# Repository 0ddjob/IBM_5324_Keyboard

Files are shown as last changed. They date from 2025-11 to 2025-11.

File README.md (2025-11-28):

# IBM System/23 Model 5324 Keyboard
Recreation of the keyboard for this computer to bring those without keyboards back to life.

## [Design References](/Design_Reference)
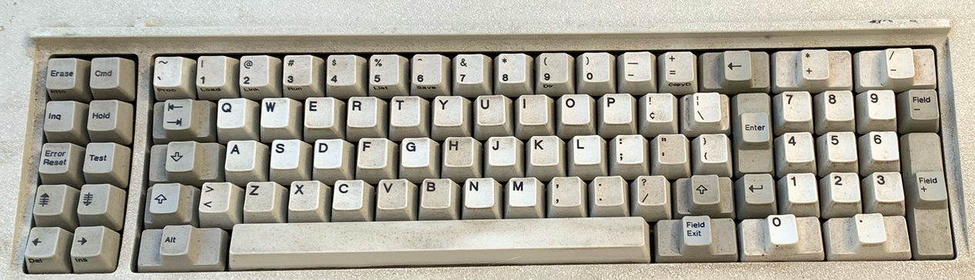
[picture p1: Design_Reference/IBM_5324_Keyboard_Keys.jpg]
Actual keyboard layout


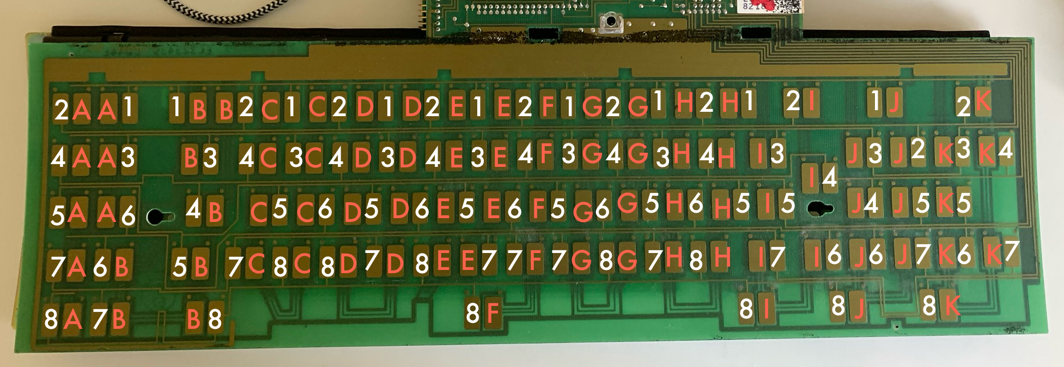
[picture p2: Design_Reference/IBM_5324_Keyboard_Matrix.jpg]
Keyboard matrix


| |Column A|Column B|Column C|Column D|Column E|Column F|Column G|Column H|Column I|Column J|Column K|
|-----|---|---|---|---|---|---|---|---|---|---|---|
|Row 1| 6F/7F  | 3E | 32 | 34 | 36 | 38 | 3A | 3C | | 4B | |
|Row 2| 7C | 31 | 33 | 35 | 37 | | 39 | 3B | 3D T | 48 | 4C |
|Row 3| 6D | 20 | 22 | 24 | 26 | | 28 | 2A | 2C | 47 | 49 |
|Row 4| 6C | 54/74  | 21 | 23 | 25 | 27 | 29 | 2B | 2D | 44 | 4E |
|Row 5| 6E | 57/77  | 11 | 13 | 15 | 17 | 19 | 1B | 59/79  | 45 | 46 |
|Row 6| 7D | 70 T | 12 | 14 | 16 | | 18 | 1A | 56/76  | 41 | 43 |
|Row 7| 71 T | 73 T | 0E | 03 | 05 | 06 | 07 | 09 | 0B/7B  | 42 | 4D |
|Row 8| 72 T | 7E/5E  | 01 | 02 | 04 | 0F T | 08 | 0A | 68/78  | 40 | 4A |

xx/yy = make/break key (send on release)<br>
T = typamatic key (repeat while held)<br>

## Keyboard Data Flow 
Refer p3-19 of the [SY34-0241-1 service manual.](/Datasheets/SY34-0241-1_IBM_5324_Computer_Service_Manual_May82_Keyboard.pdf)

The original keyboard uses a capacitive matrix where there is a capacitor for each key. When a key is pressed the capacitance increases.<br>

In my design we use standard key switches.<br>

The keyboard MCU has 11 drive lines to repeatedly scan the matrix - in my schematic these are the columns.<br>  

The increased capacitance of the active key's capacitor permits the drive-line (column) scan pulse to appear at one of the eight input lines to the sense amplifier - in my schematic these are the rows.<br>

The MCU uses the combination of the active drive line (column) and sense amplifier input line (row) to determine a scan code character (88 possible, 83 actually used).<br>

In my design the columns and rows are pulled high.  To scan the keyboard matrix we take each column low in turn.  A key press is detected when the key switch shorts the row to the column, taking the row low which is detected by the controller.  The combination of column and row is translated to a 5324 scan code and put on the bus via a buffer to ensure the 5324 accurately reads the code.<br>

An interrupt request is sent to the Model 5324 processing unit which will then read the scan code character.<br>

## Key Caps
[Key cap layout](https://gist.github.com/0ddjob/6a0642893fc0fdca74740a1e6c51e858)

|Size |Count|
|-----|-----|
|1u |68 |
|1.25u|2 |
|1.5u |2 |
|1.75u|2 |
|2u |6 |
|2.25u|1 |
|3u |1 |
|9.5u |1 |
|TOTAL|83 |

|Size|Key|
|-----|---|
|1.25u|Backslash|
|1.25u|Shift LH|
|1.5u|Shift RH|
|1.5u|Field Advance|
|1.75u|Backspace|
|1.75u|Shift Lock|
|2u|Field Exit|
|2u|NP +|
|2u|NP -|
|2u|NP 0|
|2u|NP .|
|2u|Alt|
|2u|Enter (vertical)|
|3u|Field + (vertical)|
|9.5u|Space|

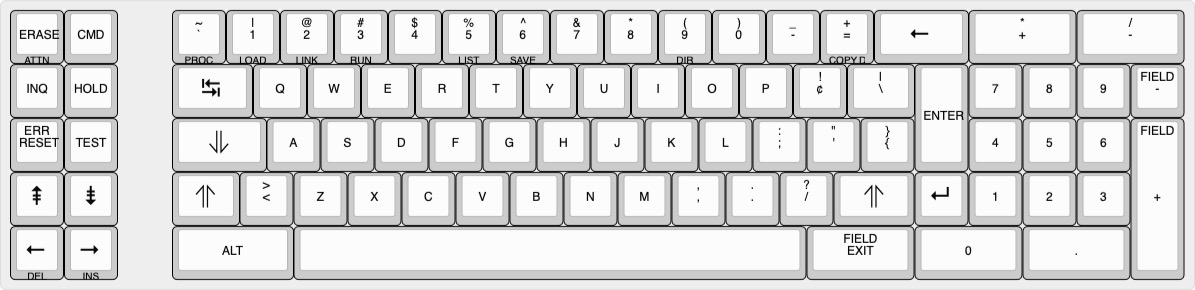
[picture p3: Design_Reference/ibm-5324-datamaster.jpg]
Keyboard layout


## [KiCad Design](/KiCad)
[Schematic](/IBM_5324_Keyboard_Schematic.pdf)

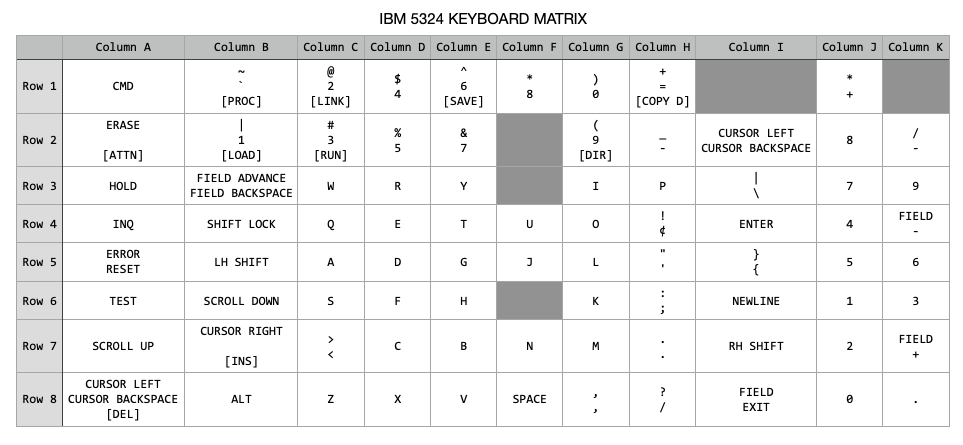
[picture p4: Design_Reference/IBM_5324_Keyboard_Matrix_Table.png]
Keyboard matrix layout


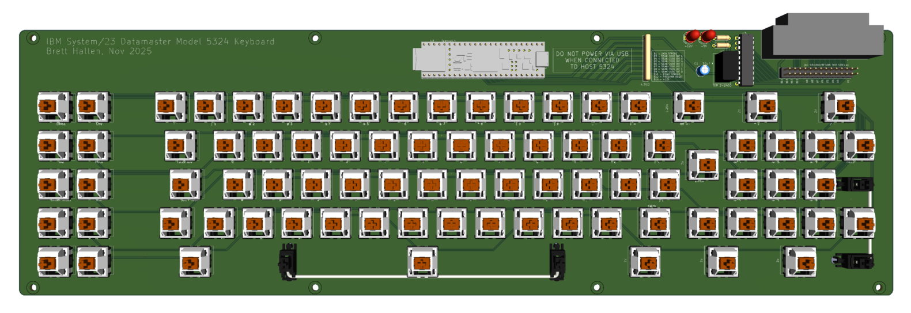
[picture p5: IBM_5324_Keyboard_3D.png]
Keyboard 3D


## [N-Key Rollover (NKRO) Design](/KiCad_NKRO)
Adding diodes to each key switch on their row connection.  The original keyboard doesn't have these so the modified behaviour might not be expected, thus it's "experimental".

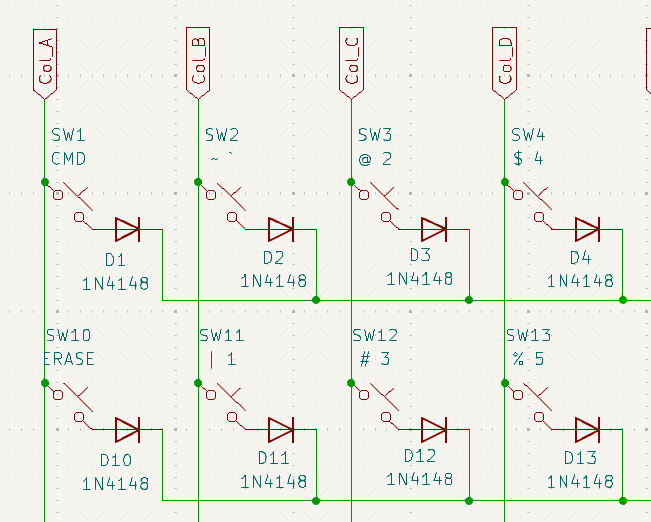
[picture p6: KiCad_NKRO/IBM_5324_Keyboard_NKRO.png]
KNRO schematic


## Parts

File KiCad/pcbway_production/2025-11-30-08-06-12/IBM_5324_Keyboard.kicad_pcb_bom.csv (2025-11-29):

Designator | Quantity | Value | Footprint | Package | MPN | DNP | Mount_Type | Description | Sim.Pins
C1 | 1 | 10µF | CP_Radial_D5.0mm_P2.50mm |  |  |  | tht | Polarized capacitor
C2, C3 | 2 | 100nF | C_Disc_D3.8mm_W2.6mm_P2.50mm |  |  |  | tht | Unpolarized capacitor
D1 | 1 | +5V | LED_D5.0mm |  |  |  | tht | Light emitting diode | 1=K 2=A
D2 | 1 | +12V | LED_D5.0mm |  |  |  | tht | Light emitting diode | 1=K 2=A
J1 | 1 | To 5324 | L717SDB25P1ACH3R |  |  |  | tht | 25-pin D-SUB connector, pins (male), Mounting Hole
J2 | 1 | To DB25 | PinHeader_2x14_P2.54mm_Vertical |  |  |  | tht | Generic connector, double row, 02x14, row letter first pin numbering scheme (pin number consists of a letter for the row and a number for the pin index in this row. a1, ..., aN; b1, ..., bN), script generated (kicad-library-utils/schlib/autogen/connector/)
KB1 | 1 | SPACE | Stabilizer_Cherry_MX_8.00u |  |  |  | tht
KB2 | 1 | FIELD+ | Stabilizer_Cherry_MX_3.00u |  |  |  | tht
R1, R2 | 2 | R | R_Axial_DIN0207_L6.3mm_D2.5mm_P7.62mm_Horizontal |  |  |  | tht | Resistor
RN1 | 1 | 4.7KΩ | R_Array_SIP9 |  |  |  | tht | 8 resistor network, star topology, bussed resistors, small symbol
SW1 | 1 | CMD | SW_Cherry_MX_PCB |  |  |  | tht | Push button switch, normally open, two pins, 45° tilted
SW10 | 1 | ERASE | SW_Cherry_MX_PCB |  |  |  | tht | Push button switch, normally open, two pins, 45° tilted
SW11 | 1 | | 1 | SW_Cherry_MX_PCB |  |  |  | tht | Push button switch, normally open, two pins, 45° tilted
SW12 | 1 | # 3 | SW_Cherry_MX_PCB |  |  |  | tht | Push button switch, normally open, two pins, 45° tilted
SW13 | 1 | % 5 | SW_Cherry_MX_PCB |  |  |  | tht | Push button switch, normally open, two pins, 45° tilted
SW14 | 1 | & 7 | SW_Cherry_MX_PCB |  |  |  | tht | Push button switch, normally open, two pins, 45° tilted
SW15 | 1 | ( 9 | SW_Cherry_MX_PCB |  |  |  | tht | Push button switch, normally open, two pins, 45° tilted
SW16 | 1 | _ - | SW_Cherry_MX_PCB |  |  |  | tht | Push button switch, normally open, two pins, 45° tilted
SW17 | 1 | RH <- | SW_Cherry_MX_PCB |  |  |  | tht | Push button switch, normally open, two pins, 45° tilted
SW18 | 1 | NP 8 | SW_Cherry_MX_PCB |  |  |  | tht | Push button switch, normally open, two pins, 45° tilted
SW19 | 1 | / - | SW_Cherry_MX_PCB_1.75u |  |  |  | tht | Push button switch, normally open, two pins, 45° tilted
SW2 | 1 | ~ ` | SW_Cherry_MX_PCB |  |  |  | tht | Push button switch, normally open, two pins, 45° tilted
SW20 | 1 | HOLD | SW_Cherry_MX_PCB |  |  |  | tht | Push button switch, normally open, two pins, 45° tilted
SW21 | 1 | FIELD ADV | SW_Cherry_MX_PCB_1.50u |  |  |  | tht | Push button switch, normally open, two pins, 45° tilted
SW22 | 1 | W | SW_Cherry_MX_PCB |  |  |  | tht | Push button switch, normally open, two pins, 45° tilted
SW23 | 1 | R | SW_Cherry_MX_PCB |  |  |  | tht | Push button switch, normally open, two pins, 45° tilted
SW24 | 1 | Y | SW_Cherry_MX_PCB |  |  |  | tht | Push button switch, normally open, two pins, 45° tilted
SW25 | 1 | I | SW_Cherry_MX_PCB |  |  |  | tht | Push button switch, normally open, two pins, 45° tilted
SW26 | 1 | P | SW_Cherry_MX_PCB |  |  |  | tht | Push button switch, normally open, two pins, 45° tilted
SW27 | 1 | | \ | SW_Cherry_MX_PCB |  |  |  | tht | Push button switch, normally open, two pins, 45° tilted
SW28 | 1 | NP 7 | SW_Cherry_MX_PCB |  |  |  | tht | Push button switch, normally open, two pins, 45° tilted
SW29 | 1 | NP 9 | SW_Cherry_MX_PCB |  |  |  | tht | Push button switch, normally open, two pins, 45° tilted
SW3 | 1 | @ 2 | SW_Cherry_MX_PCB |  |  |  | tht | Push button switch, normally open, two pins, 45° tilted
SW30 | 1 | INQ | SW_Cherry_MX_PCB |  |  |  | tht | Push button switch, normally open, two pins, 45° tilted
SW31 | 1 | SHIFT LOCK | SW_Cherry_MX_PCB_1.75u |  |  |  | tht | Push button switch, normally open, two pins, 45° tilted
SW32 | 1 | Q | SW_Cherry_MX_PCB |  |  |  | tht | Push button switch, normally open, two pins, 45° tilted
SW33 | 1 | E | SW_Cherry_MX_PCB |  |  |  | tht | Push button switch, normally open, two pins, 45° tilted
SW34 | 1 | T | SW_Cherry_MX_PCB |  |  |  | tht | Push button switch, normally open, two pins, 45° tilted
SW35 | 1 | U | SW_Cherry_MX_PCB |  |  |  | tht | Push button switch, normally open, two pins, 45° tilted
SW36 | 1 | O | SW_Cherry_MX_PCB |  |  |  | tht | Push button switch, normally open, two pins, 45° tilted
SW37 | 1 | ! ¢ | SW_Cherry_MX_PCB |  |  |  | tht | Push button switch, normally open, two pins, 45° tilted
SW38 | 1 | ENTER | SW_Cherry_MX_PCB_2.00u_90deg |  |  |  | tht | Push button switch, normally open, two pins, 45° tilted
SW39 | 1 | NP 4 | SW_Cherry_MX_PCB |  |  |  | tht | Push button switch, normally open, two pins, 45° tilted
SW4 | 1 | $ 4 | SW_Cherry_MX_PCB |  |  |  | tht | Push button switch, normally open, two pins, 45° tilted
SW40 | 1 | FIELD- | SW_Cherry_MX_PCB |  |  |  | tht | Push button switch, normally open, two pins, 45° tilted
SW41 | 1 | ERROR RESET | SW_Cherry_MX_PCB |  |  |  | tht | Push button switch, normally open, two pins, 45° tilted
SW42 | 1 | LH SHIFT | SW_Cherry_MX_PCB_1.25u |  |  |  | tht | Push button switch, normally open, two pins, 45° tilted
SW43 | 1 | A | SW_Cherry_MX_PCB |  |  |  | tht | Push button switch, normally open, two pins, 45° tilted
SW44 | 1 | D | SW_Cherry_MX_PCB |  |  |  | tht | Push button switch, normally open, two pins, 45° tilted
SW45 | 1 | G | SW_Cherry_MX_PCB |  |  |  | tht | Push button switch, normally open, two pins, 45° tilted
SW46 | 1 | J | SW_Cherry_MX_PCB |  |  |  | tht | Push button switch, normally open, two pins, 45° tilted
SW47 | 1 | L | SW_Cherry_MX_PCB |  |  |  | tht | Push button switch, normally open, two pins, 45° tilted
SW48 | 1 | " ' | SW_Cherry_MX_PCB |  |  |  | tht | Push button switch, normally open, two pins, 45° tilted
SW49 | 1 | } { | SW_Cherry_MX_PCB |  |  |  | tht | Push button switch, normally open, two pins, 45° tilted
SW5 | 1 | ^ 6 | SW_Cherry_MX_PCB |  |  |  | tht | Push button switch, normally open, two pins, 45° tilted
SW50 | 1 | NP 5 | SW_Cherry_MX_PCB |  |  |  | tht | Push button switch, normally open, two pins, 45° tilted
SW51 | 1 | NP 6 | SW_Cherry_MX_PCB |  |  |  | tht | Push button switch, normally open, two pins, 45° tilted
SW52 | 1 | TEST | SW_Cherry_MX_PCB |  |  |  | tht | Push button switch, normally open, two pins, 45° tilted
SW53 | 1 | SCROLL DOWN | SW_Cherry_MX_PCB |  |  |  | tht | Push button switch, normally open, two pins, 45° tilted
SW54 | 1 | S | SW_Cherry_MX_PCB |  |  |  | tht | Push button switch, normally open, two pins, 45° tilted
SW55 | 1 | F | SW_Cherry_MX_PCB |  |  |  | tht | Push button switch, normally open, two pins, 45° tilted
SW56 | 1 | H | SW_Cherry_MX_PCB |  |  |  | tht | Push button switch, normally open, two pins, 45° tilted
SW57 | 1 | K | SW_Cherry_MX_PCB |  |  |  | tht | Push button switch, normally open, two pins, 45° tilted
SW58 | 1 | : ; | SW_Cherry_MX_PCB |  |  |  | tht | Push button switch, normally open, two pins, 45° tilted
SW59 | 1 | NEWLINE | SW_Cherry_MX_PCB |  |  |  | tht | Push button switch, normally open, two pins, 45° tilted
SW6 | 1 | * 8 | SW_Cherry_MX_PCB |  |  |  | tht | Push button switch, normally open, two pins, 45° tilted
SW60 | 1 | NP 1 | SW_Cherry_MX_PCB |  |  |  | tht | Push button switch, normally open, two pins, 45° tilted
SW61 | 1 | NP 3 | SW_Cherry_MX_PCB |  |  |  | tht | Push button switch, normally open, two pins, 45° tilted
SW62 | 1 | SCROLL UP | SW_Cherry_MX_PCB |  |  |  | tht | Push button switch, normally open, two pins, 45° tilted
SW63 | 1 | -> | SW_Cherry_MX_PCB |  |  |  | tht | Push button switch, normally open, two pins, 45° tilted
SW64 | 1 | > < | SW_Cherry_MX_PCB_1.00u |  |  |  | tht | Push button switch, normally open, two pins, 45° tilted
SW65 | 1 | C | SW_Cherry_MX_PCB |  |  |  | tht | Push button switch, normally open, two pins, 45° tilted
SW66 | 1 | B | SW_Cherry_MX_PCB |  |  |  | tht | Push button switch, normally open, two pins, 45° tilted
SW67 | 1 | N | SW_Cherry_MX_PCB |  |  |  | tht | Push button switch, normally open, two pins, 45° tilted
SW68 | 1 | M | SW_Cherry_MX_PCB |  |  |  | tht | Push button switch, normally open, two pins, 45° tilted
SW69 | 1 | . . | SW_Cherry_MX_PCB |  |  |  | tht | Push button switch, normally open, two pins, 45° tilted
SW7 | 1 | ) 0 | SW_Cherry_MX_PCB |  |  |  | tht | Push button switch, normally open, two pins, 45° tilted
SW70 | 1 | RH SHIFT | SW_Cherry_MX_PCB_1.50u |  |  |  | tht | Push button switch, normally open, two pins, 45° tilted
SW71 | 1 | NP 2 | SW_Cherry_MX_PCB |  |  |  | tht | Push button switch, normally open, two pins, 45° tilted
SW72 | 1 | FIELD+ | SW_Cherry_MX_PCB_3.00u_90deg |  |  |  | tht | Push button switch, normally open, two pins, 45° tilted
SW73 | 1 | LH <- | SW_Cherry_MX_PCB |  |  |  | tht | Push button switch, normally open, two pins, 45° tilted
SW74 | 1 | ALT | SW_Cherry_MX_PCB_2.25u |  |  |  | tht | Push button switch, normally open, two pins, 45° tilted
SW75 | 1 | Z | SW_Cherry_MX_PCB |  |  |  | tht | Push button switch, normally open, two pins, 45° tilted
SW76 | 1 | X | SW_Cherry_MX_PCB |  |  |  | tht | Push button switch, normally open, two pins, 45° tilted
SW77 | 1 | V | SW_Cherry_MX_PCB |  |  |  | tht | Push button switch, normally open, two pins, 45° tilted
SW78 | 1 | SPACE | SW_Cherry_MX_PCB |  |  |  | tht | Push button switch, normally open, two pins, 45° tilted
SW79 | 1 | , , | SW_Cherry_MX_PCB |  |  |  | tht | Push button switch, normally open, two pins, 45° tilted
SW8 | 1 | + = | SW_Cherry_MX_PCB |  |  |  | tht | Push button switch, normally open, two pins, 45° tilted
SW80 | 1 | ? / | SW_Cherry_MX_PCB |  |  |  | tht | Push button switch, normally open, two pins, 45° tilted
SW81 | 1 | FIELD EXIT | SW_Cherry_MX_PCB_2.00u |  |  |  | tht | Push button switch, normally open, two pins, 45° tilted
SW82 | 1 | NP 0 | SW_Cherry_MX_PCB_2.00u |  |  |  | tht | Push button switch, normally open, two pins, 45° tilted
SW83 | 1 | NP . | SW_Cherry_MX_PCB_2.00u |  |  |  | tht | Push button switch, normally open, two pins, 45° tilted
SW9 | 1 | * + | SW_Cherry_MX_PCB_1.75u |  |  |  | tht | Push button switch, normally open, two pins, 45° tilted
U1 | 1 | Teensy4.1 | Teensy41 |  |  |  | tht
U2 | 1 | TSR 2-2450 | Converter_DCDC_TRACO_TSR2-24xxN_TSR2-24xxxN_THT |  |  |  | tht | Positive 1A 35V Linear Regulator, Fixed Output 5V, TO-220
U3 | 1 | 74HCT245 | DIP-20_W7.62mm |  |  |  | tht | Octal BUS Transceivers, 3-State outputs
U4 | 1 | 74HCT125 | DIP-14_W7.62mm |  |  |  | tht | Quad buffer 3-State outputs

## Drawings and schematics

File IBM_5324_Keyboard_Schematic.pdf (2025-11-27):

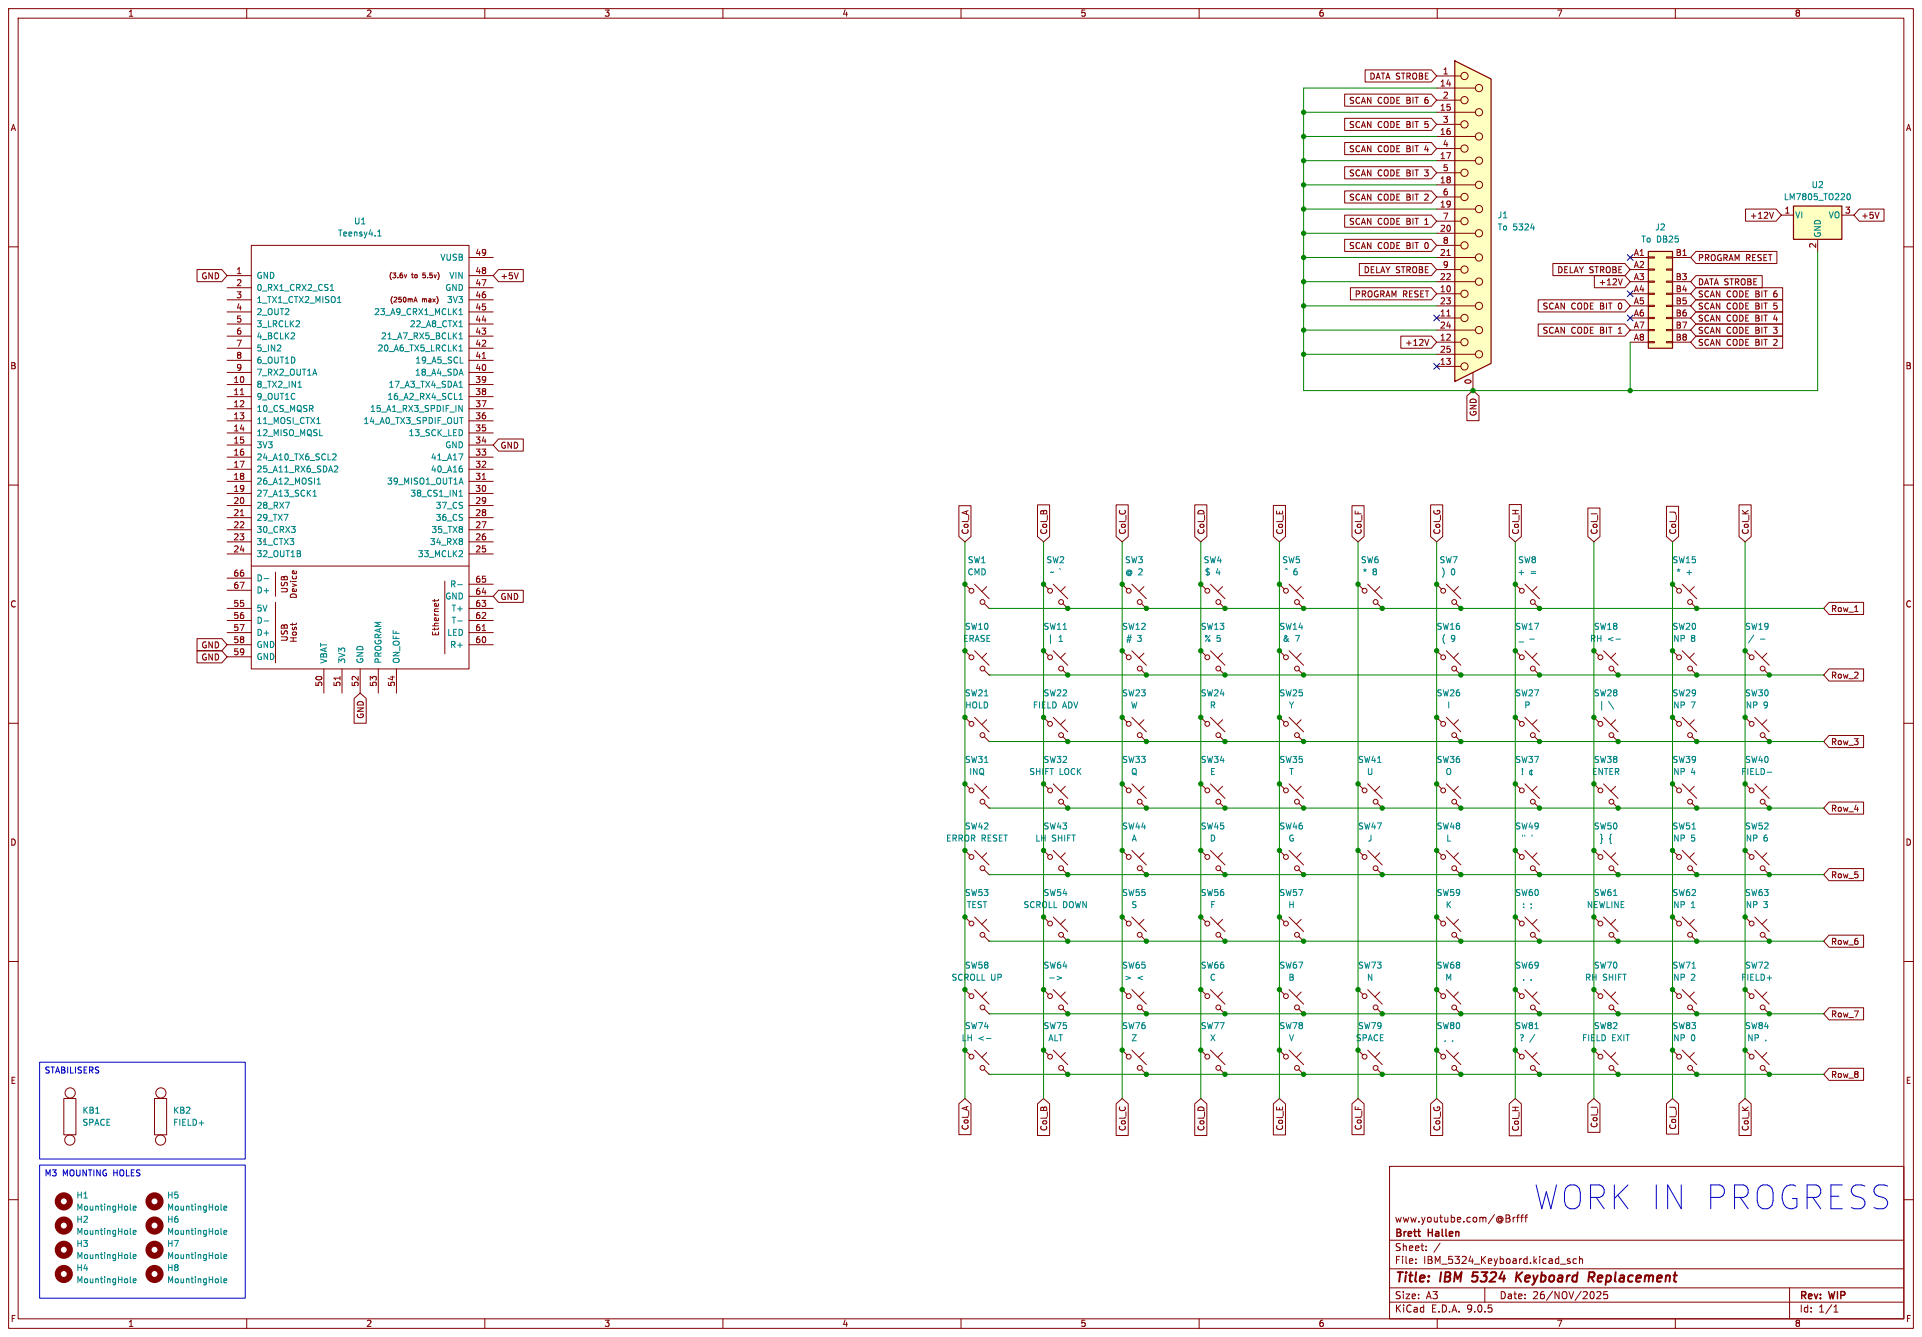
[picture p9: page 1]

SCAN CODE BIT 1 SCAN CODE BIT 4 SCAN CODE BIT 5 SCAN CODE BIT 6 DATA STROBE

LM7805_TO220 USB USB Device Host

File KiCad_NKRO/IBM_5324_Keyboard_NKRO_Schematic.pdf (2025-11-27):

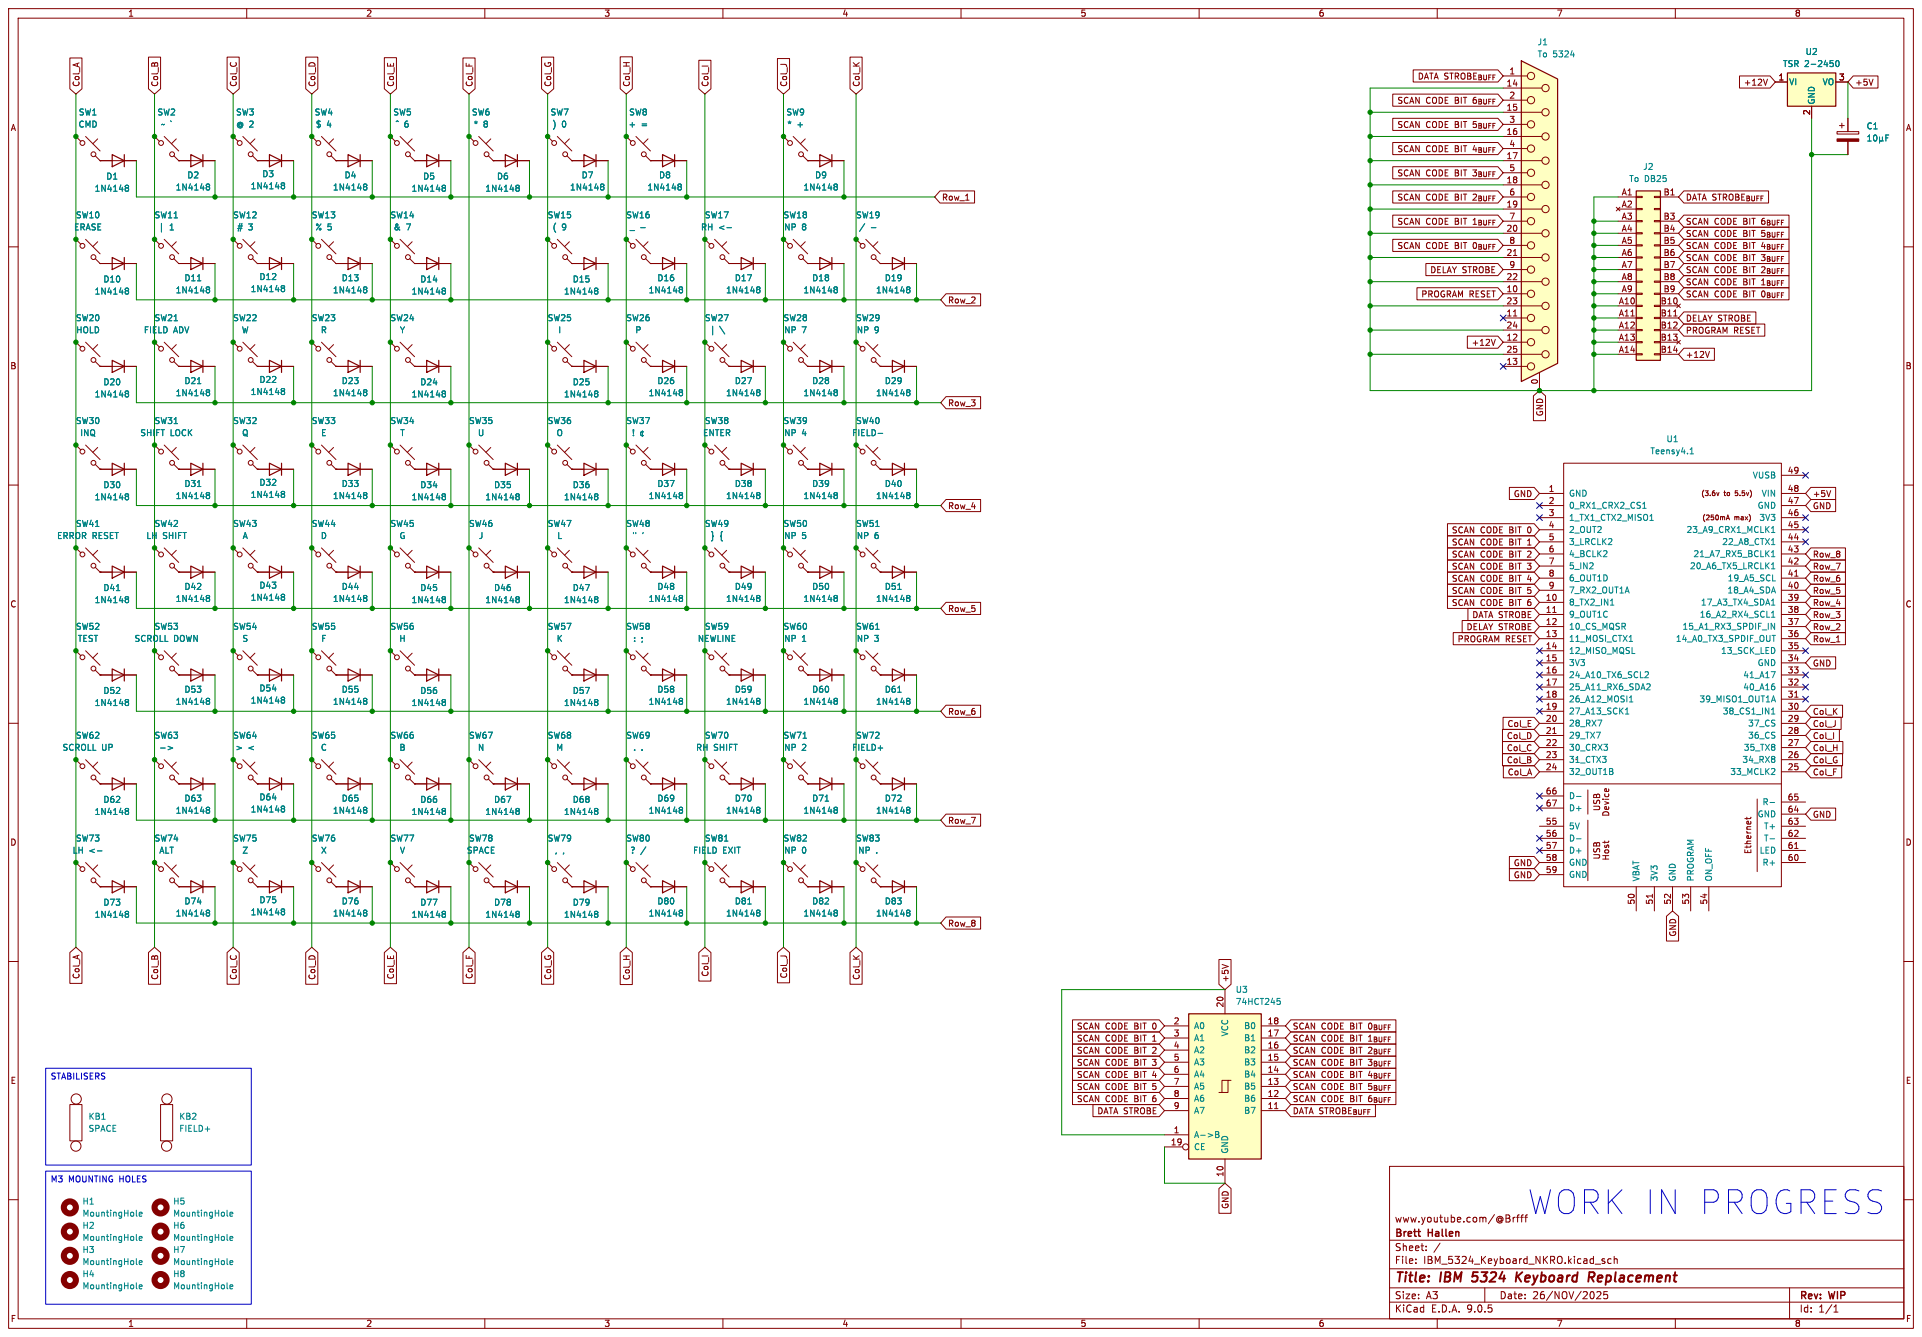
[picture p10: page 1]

SCAN CODE BIT 3_{BUFF} SCAN CODE BIT 4_{BUFF} SCAN CODE BIT 5_{BUFF} SCAN CODE BIT 2_{BUFF} SCAN CODE BIT 1_{BUFF} SCAN CODE BIT 6_{BUFF} DATA STROBE_{BUFF} SCAN CODE BIT 5_{BUFF} SCAN CODE BIT 4_{BUFF} SCAN CODE BIT 2_{BUFF} SCAN CODE BIT 3_{BUFF} +12V

SCAN CODE BIT 1_{BUFF} SCAN CODE BIT 0_{BUFF} GND

SCAN CODE BIT 0_{BUFF} SCAN CODE BIT 6_{BUFF} DATA STROBE_{BUFF} PROGRAM RESET DELAY STROBE

60 GND 1
0_RX1_CRX2_CS1 2
1_TX1_CTX2_MISO1 3
(250mA max) Ethernet 3_LRCLK2 5
SCAN CODE BIT 5 SCAN CODE BIT 4 SCAN CODE BIT 1 SCAN CODE BIT 0 SCAN CODE BIT 2 SCAN CODE BIT 3 GND GND

SCAN CODE BIT 6 DELAY STROBE
Row_1 Row_2 PROGRAM RESET DATA STROBE

LH <- SW52 TEST SW62 SCROLL UP

DATA STROBE_{BUFF} SCAN CODE BIT 3_{BUFF} SCAN CODE BIT 5_{BUFF} SCAN CODE BIT 4_{BUFF} SCAN CODE BIT 6_{BUFF} SCAN CODE BIT 0_{BUFF} +5V

SCAN CODE BIT 1_{BUFF} SCAN CODE BIT 2_{BUFF}

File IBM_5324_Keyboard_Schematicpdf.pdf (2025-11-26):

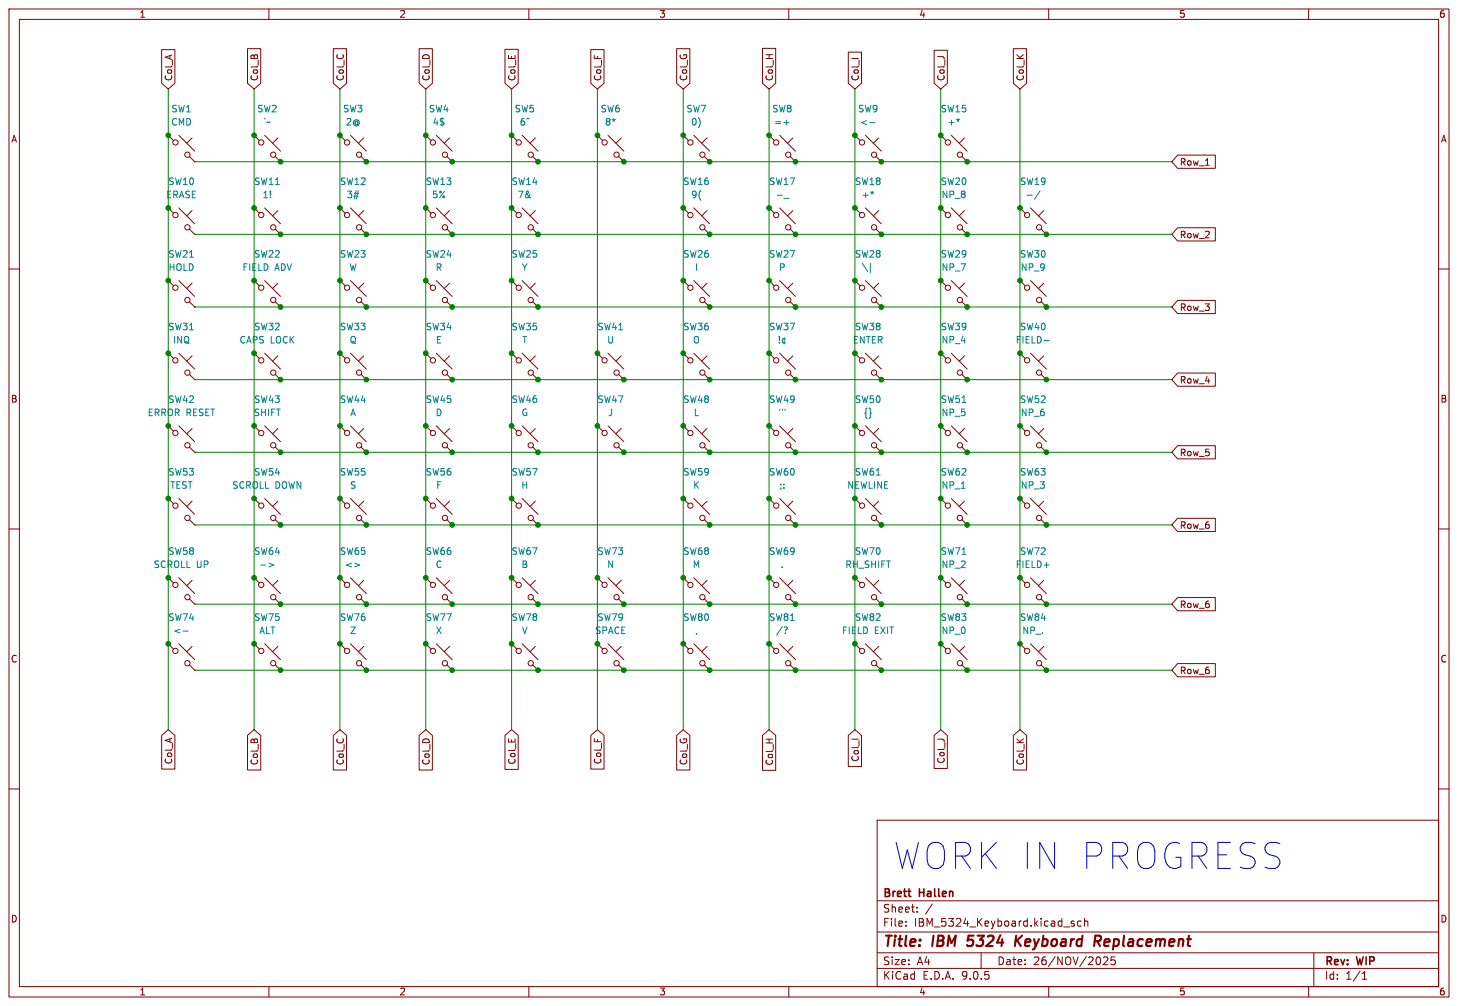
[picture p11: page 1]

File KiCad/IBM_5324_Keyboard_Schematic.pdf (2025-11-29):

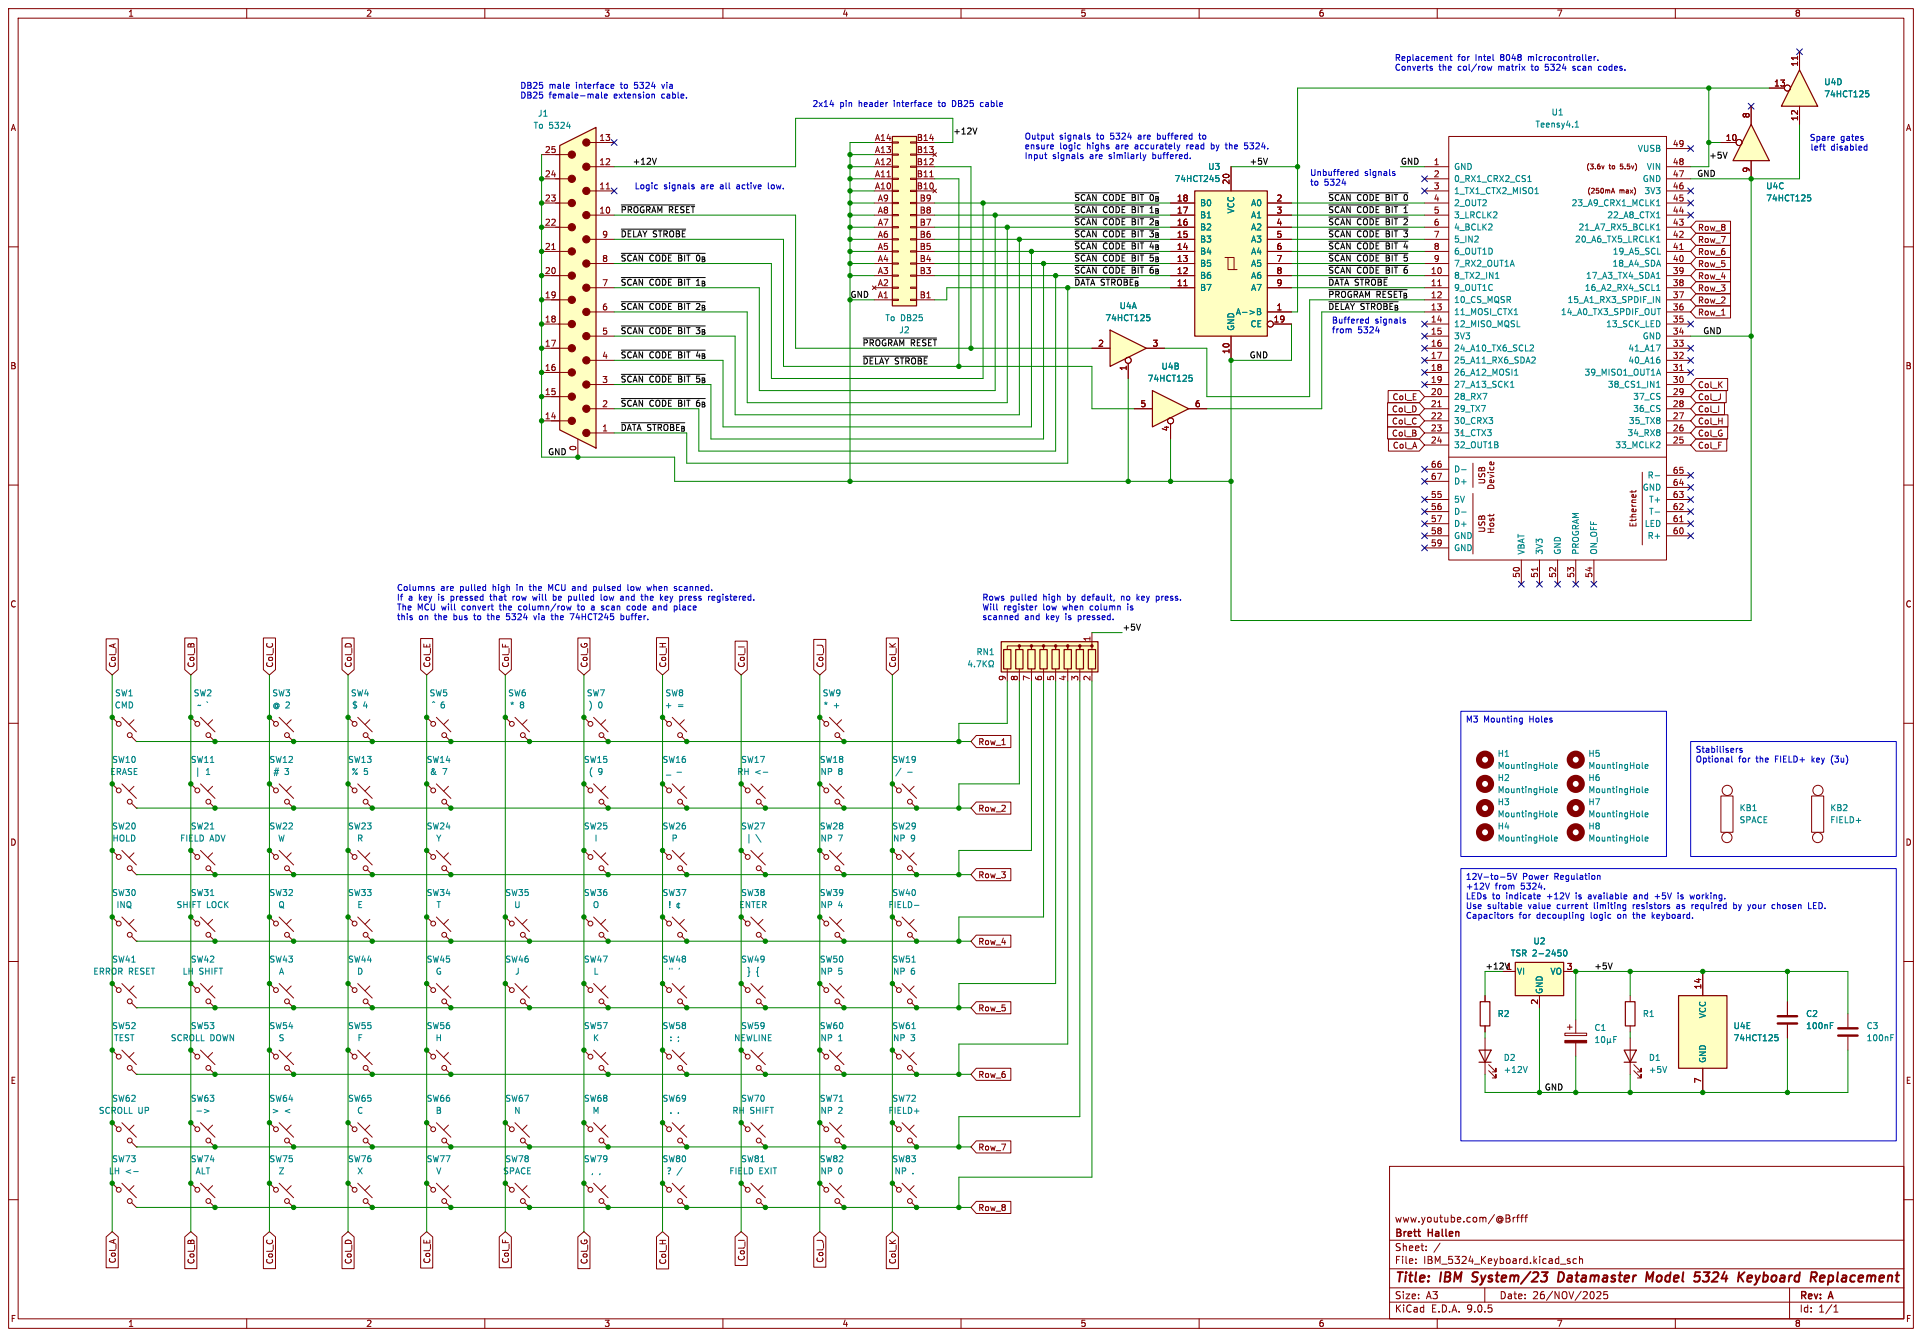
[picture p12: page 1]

this on the bus to the 5324 via the 74HCT245 buffer.

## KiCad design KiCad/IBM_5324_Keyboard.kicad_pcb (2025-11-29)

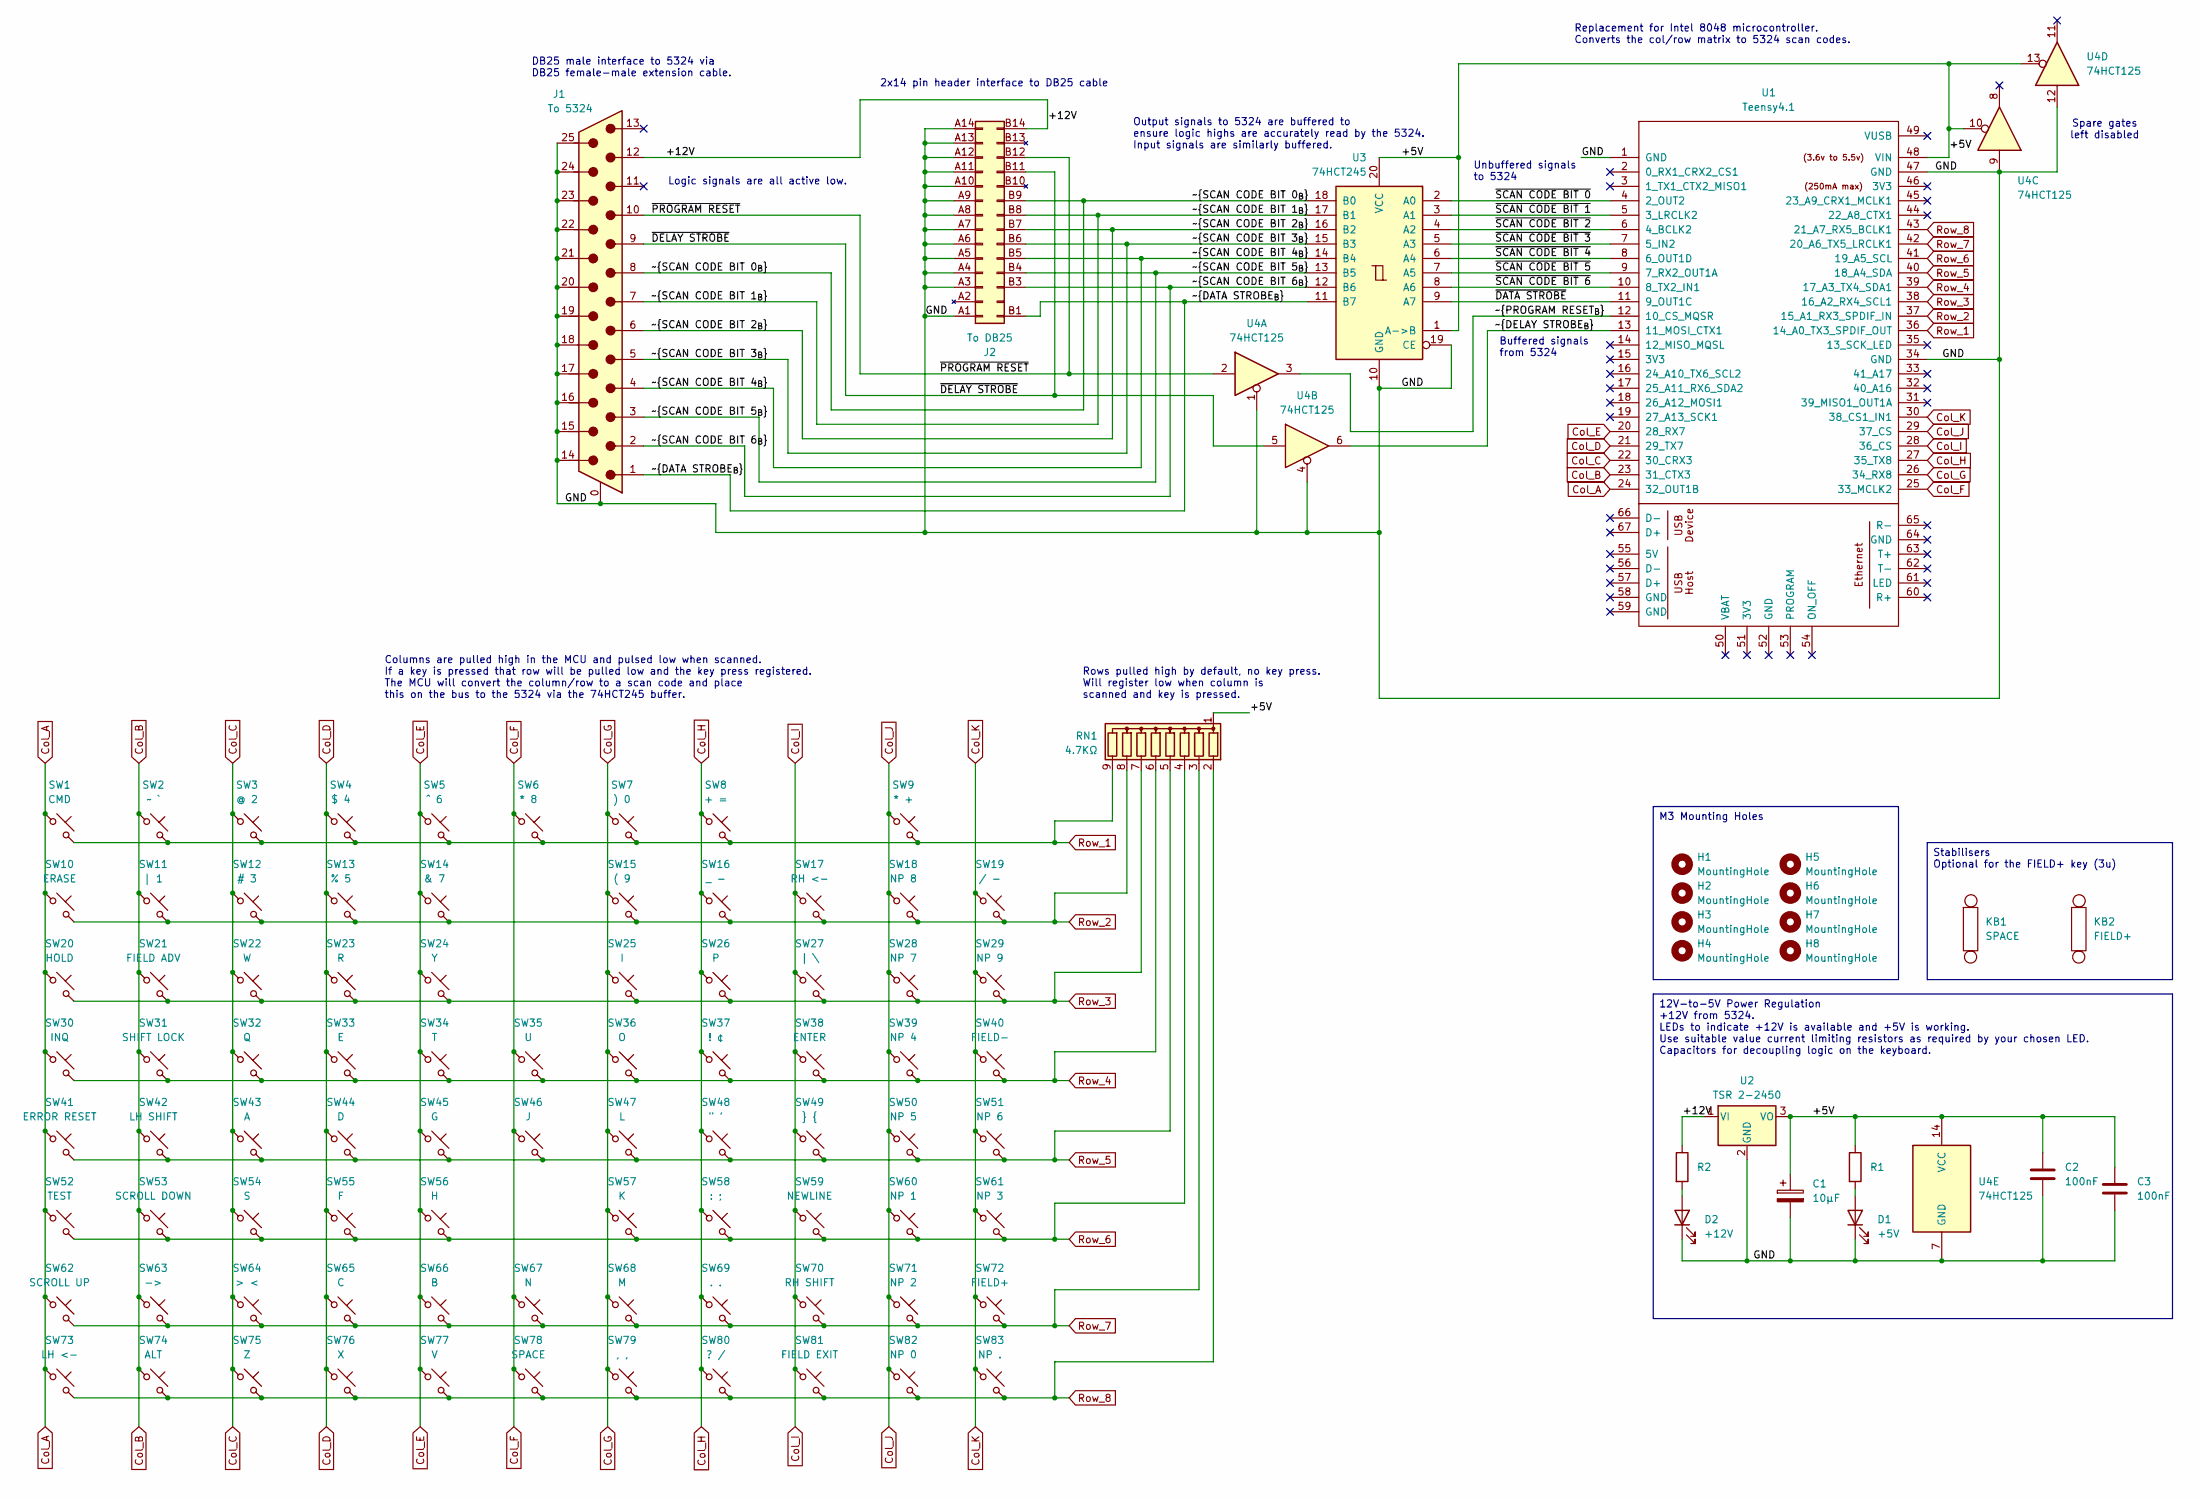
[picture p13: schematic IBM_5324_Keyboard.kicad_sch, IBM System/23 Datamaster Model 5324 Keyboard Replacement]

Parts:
C1: 10µF; CP_Radial_D5.0mm_P2.50mm
C2, C3: 100nF; C_Disc_D3.8mm_W2.6mm_P2.50mm
D1: +5V; LED_D5.0mm
D2: +12V; LED_D5.0mm
H1, H2, H3, H4, H5, H6, H7, H8: MountingHole; MountingHole_3.2mm_M3
J1: To 5324; L717SDB25P1ACH3R
J2: To DB25; PinHeader_2x14_P2.54mm_Vertical
KB1: SPACE; Stabilizer_Cherry_MX_8.00u
KB2: FIELD+; Stabilizer_Cherry_MX_3.00u
R1, R2: R; R_Axial_DIN0207_L6.3mm_D2.5mm_P7.62mm_Horizontal
RN1: 4.7KΩ; R_Array_SIP9
SW1: CMD; SW_Cherry_MX_PCB
SW2: ~ `; SW_Cherry_MX_PCB
SW3: @ 2; SW_Cherry_MX_PCB
SW4: $ 4; SW_Cherry_MX_PCB
SW5: ^ 6; SW_Cherry_MX_PCB
SW6: * 8; SW_Cherry_MX_PCB
SW7: ) 0; SW_Cherry_MX_PCB
SW8: + =; SW_Cherry_MX_PCB
SW9: * +; SW_Cherry_MX_PCB_1.75u
SW10: ERASE; SW_Cherry_MX_PCB
SW11: | 1; SW_Cherry_MX_PCB
SW12: # 3; SW_Cherry_MX_PCB
SW13: % 5; SW_Cherry_MX_PCB
SW14: & 7; SW_Cherry_MX_PCB
SW15: ( 9; SW_Cherry_MX_PCB
SW16: _ -; SW_Cherry_MX_PCB
SW17: RH <-; SW_Cherry_MX_PCB
SW18: NP 8; SW_Cherry_MX_PCB
SW19: / -; SW_Cherry_MX_PCB_1.75u
SW20: HOLD; SW_Cherry_MX_PCB
SW21: FIELD ADV; SW_Cherry_MX_PCB_1.50u
SW22: W; SW_Cherry_MX_PCB
SW23: R; SW_Cherry_MX_PCB
SW24: Y; SW_Cherry_MX_PCB
SW25: I; SW_Cherry_MX_PCB
SW26: P; SW_Cherry_MX_PCB
SW27: | \; SW_Cherry_MX_PCB
SW28: NP 7; SW_Cherry_MX_PCB
SW29: NP 9; SW_Cherry_MX_PCB
SW30: INQ; SW_Cherry_MX_PCB
SW31: SHIFT LOCK; SW_Cherry_MX_PCB_1.75u
SW32: Q; SW_Cherry_MX_PCB
SW33: E; SW_Cherry_MX_PCB
SW34: T; SW_Cherry_MX_PCB
SW35: U; SW_Cherry_MX_PCB
SW36: O; SW_Cherry_MX_PCB
SW37: ! ¢; SW_Cherry_MX_PCB
SW38: ENTER; SW_Cherry_MX_PCB_2.00u_90deg
SW39: NP 4; SW_Cherry_MX_PCB
SW40: FIELD-; SW_Cherry_MX_PCB
SW41: ERROR RESET; SW_Cherry_MX_PCB
SW42: LH SHIFT; SW_Cherry_MX_PCB_1.25u
SW43: A; SW_Cherry_MX_PCB
SW44: D; SW_Cherry_MX_PCB
SW45: G; SW_Cherry_MX_PCB
SW46: J; SW_Cherry_MX_PCB
SW47: L; SW_Cherry_MX_PCB
SW48: " '; SW_Cherry_MX_PCB
SW49: } {; SW_Cherry_MX_PCB
SW50: NP 5; SW_Cherry_MX_PCB
SW51: NP 6; SW_Cherry_MX_PCB
SW52: TEST; SW_Cherry_MX_PCB
SW53: SCROLL DOWN; SW_Cherry_MX_PCB
SW54: S; SW_Cherry_MX_PCB
SW55: F; SW_Cherry_MX_PCB
SW56: H; SW_Cherry_MX_PCB
SW57: K; SW_Cherry_MX_PCB
SW58: : ;; SW_Cherry_MX_PCB
SW59: NEWLINE; SW_Cherry_MX_PCB
SW60: NP 1; SW_Cherry_MX_PCB
SW61: NP 3; SW_Cherry_MX_PCB
SW62: SCROLL UP; SW_Cherry_MX_PCB
SW63: ->; SW_Cherry_MX_PCB
SW64: > <; SW_Cherry_MX_PCB_1.00u
SW65: C; SW_Cherry_MX_PCB
SW66: B; SW_Cherry_MX_PCB
SW67: N; SW_Cherry_MX_PCB
SW68: M; SW_Cherry_MX_PCB
SW69: . .; SW_Cherry_MX_PCB
SW70: RH SHIFT; SW_Cherry_MX_PCB_1.50u
SW71: NP 2; SW_Cherry_MX_PCB
SW72: FIELD+; SW_Cherry_MX_PCB_3.00u_90deg
SW73: LH <-; SW_Cherry_MX_PCB
SW74: ALT; SW_Cherry_MX_PCB_2.25u
SW75: Z; SW_Cherry_MX_PCB
SW76: X; SW_Cherry_MX_PCB
SW77: V; SW_Cherry_MX_PCB
SW78: SPACE; SW_Cherry_MX_PCB
SW79: , ,; SW_Cherry_MX_PCB
SW80: ? /; SW_Cherry_MX_PCB
SW81: FIELD EXIT; SW_Cherry_MX_PCB_2.00u
SW82: NP 0; SW_Cherry_MX_PCB_2.00u
SW83: NP .; SW_Cherry_MX_PCB_2.00u
U1: Teensy4.1; Teensy41
U2: TSR 2-2450; Converter_DCDC_TRACO_TSR2-24xxN_TSR2-24xxxN_THT
U3: 74HCT245; DIP-20_W7.62mm
U4: 74HCT125; DIP-14_W7.62mm

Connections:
/+5V: C1.1, C2.1, C3.1, R1.1, RN1.1 (common), U1.48 (VIN), U2.3 (VO), U3.1 (A->B), U3.20 (VCC), U4.10, U4.13, U4.14 (VCC)
/+12V: J1.12, J2.B14 (+12V), R2.1, U2.1 (VI)
/GND: C1.2, C2.2, C3.2, D1.1 (K), D2.1 (K), J1.0 (PAD), J1.14, J1.15, J1.16, J1.17, J1.18, J1.19, J1.20, J1.21, J1.22, J1.23, J1.24, J1.25, J2.A1 (GND), J2.A3 (GND), J2.A4 (GND), J2.A5 (GND), J2.A6 (GND), J2.A7 (GND), J2.A8 (GND), J2.A9 (GND), J2.A10 (GND), J2.A11 (GND), J2.A12 (GND), J2.A13 (GND), J2.A14 (GND), U1.1 (GND), U1.34 (GND), U1.47 (GND), U2.2 (GND), U3.10 (GND), U3.19 (CE), U4.1, U4.4, U4.7 (GND), U4.9, U4.12
/~DATA STROBE_{B}: J1.1, J2.B1 (DATA_STROBE), U3.11 (B7)
/~DATA STROBE: U1.11 (9_OUT1C), U3.9 (A7)
/~DELAY STROBE_{B}: U1.13 (11_MOSI_CTX1), U4.6
/~DELAY STROBE: J1.9, J2.B11 (DELAY_STROBE), U4.5
/~PROGRAM RESET_{B}: U1.12 (10_CS_MQSR), U4.3
/~PROGRAM RESET: J1.10, J2.B12 (PROGRAM_RESET), U4.2
/~SCAN CODE BIT 0_{B}: J1.8, J2.B9 (SCAN_CODE_BIT_0), U3.18 (B0)
/~SCAN CODE BIT 0: U1.4 (2_OUT2), U3.2 (A0)
/~SCAN CODE BIT 1_{B}: J1.7, J2.B8 (SCAN_CODE_BIT_1), U3.17 (B1)
/~SCAN CODE BIT 1: U1.5 (3_LRCLK2), U3.3 (A1)
/~SCAN CODE BIT 2_{B}: J1.6, J2.B7 (SCAN_CODE_BIT_2), U3.16 (B2)
/~SCAN CODE BIT 2: U1.6 (4_BCLK2), U3.4 (A2)
/~SCAN CODE BIT 3_{B}: J1.5, J2.B6 (SCAN_CODE_BIT_3), U3.15 (B3)
/~SCAN CODE BIT 3: U1.7 (5_IN2), U3.5 (A3)
/~SCAN CODE BIT 4_{B}: J1.4, J2.B5 (SCAN_CODE_BIT_4), U3.14 (B4)
/~SCAN CODE BIT 4: U1.8 (6_OUT1D), U3.6 (A4)
/~SCAN CODE BIT 5_{B}: J1.3, J2.B4 (SCAN_CODE_BIT_5), U3.13 (B5)
/~SCAN CODE BIT 5: U1.9 (7_RX2_OUT1A), U3.7 (A5)
/~SCAN CODE BIT 6_{B}: J1.2, J2.B3 (SCAN_CODE_BIT_6), U3.12 (B6)
/~SCAN CODE BIT 6: U1.10 (8_TX2_IN1), U3.8 (A6)
Col_A: SW1.1, SW10.1, SW20.1, SW30.1, SW41.1, SW52.1, SW62.1, SW73.1, U1.24 (32_OUT1B)
Col_B: SW2.1, SW11.1, SW21.1, SW31.1, SW42.1, SW53.1, SW63.1, SW74.1, U1.23 (31_CTX3)
Col_C: SW3.1, SW12.1, SW22.1, SW32.1, SW43.1, SW54.1, SW64.1, SW75.1, U1.22 (30_CRX3)
Col_D: SW4.1, SW13.1, SW23.1, SW33.1, SW44.1, SW55.1, SW65.1, SW76.1, U1.21 (29_TX7)
Col_E: SW5.1, SW14.1, SW24.1, SW34.1, SW45.1, SW56.1, SW66.1, SW77.1, U1.20 (28_RX7)
Col_F: SW6.1, SW35.1, SW46.1, SW67.1, SW78.1, U1.25 (33_MCLK2)
Col_G: SW7.1, SW15.1, SW25.1, SW36.1, SW47.1, SW57.1, SW68.1, SW79.1, U1.26 (34_RX8)
Col_H: SW8.1, SW16.1, SW26.1, SW37.1, SW48.1, SW58.1, SW69.1, SW80.1, U1.27 (35_TX8)
Col_I: SW17.1, SW27.1, SW38.1, SW49.1, SW59.1, SW70.1, SW81.1, U1.28 (36_CS)
Col_J: SW9.1, SW18.1, SW28.1, SW39.1, SW50.1, SW60.1, SW71.1, SW82.1, U1.29 (37_CS)
Col_K: SW19.1, SW29.1, SW40.1, SW51.1, SW61.1, SW72.1, SW83.1, U1.30 (38_CS1_IN1)
unnamed: D1.2 (A), R1.2
unnamed: D2.2 (A), R2.2
Row_1: RN1.9 (R8), SW1.2, SW2.2, SW3.2, SW4.2, SW5.2, SW6.2, SW7.2, SW8.2, SW9.2, U1.36 (14_A0_TX3_SPDIF_OUT)
Row_2: RN1.8 (R7), SW10.2, SW11.2, SW12.2, SW13.2, SW14.2, SW15.2, SW16.2, SW17.2, SW18.2, SW19.2, U1.37 (15_A1_RX3_SPDIF_IN)
Row_3: RN1.7 (R6), SW20.2, SW21.2, SW22.2, SW23.2, SW24.2, SW25.2, SW26.2, SW27.2, SW28.2, SW29.2, U1.38 (16_A2_RX4_SCL1)
Row_4: RN1.6 (R5), SW30.2, SW31.2, SW32.2, SW33.2, SW34.2, SW35.2, SW36.2, SW37.2, SW38.2, SW39.2, SW40.2, U1.39 (17_A3_TX4_SDA1)
Row_5: RN1.5 (R4), SW41.2, SW42.2, SW43.2, SW44.2, SW45.2, SW46.2, SW47.2, SW48.2, SW49.2, SW50.2, SW51.2, U1.40 (18_A4_SDA)
Row_6: RN1.4 (R3), SW52.2, SW53.2, SW54.2, SW55.2, SW56.2, SW57.2, SW58.2, SW59.2, SW60.2, SW61.2, U1.41 (19_A5_SCL)
Row_7: RN1.3 (R2), SW62.2, SW63.2, SW64.2, SW65.2, SW66.2, SW67.2, SW68.2, SW69.2, SW70.2, SW71.2, SW72.2, U1.42 (20_A6_TX5_LRCLK1)
Row_8: RN1.2 (R1), SW73.2, SW74.2, SW75.2, SW76.2, SW77.2, SW78.2, SW79.2, SW80.2, SW81.2, SW82.2, SW83.2, U1.43 (21_A7_RX5_BCLK1)

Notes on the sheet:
Columns are pulled high in the MCU and pulsed low when scanned. If a key is pressed that row will be pulled low and the key press registered. The MCU will convert the column/row to a scan code and place this on the bus to the 5324 via the 74HCT245 buffer.
Buffered signals from 5324
Spare gates left disabled
Logic signals are all active low.
2x14 pin header interface to DB25 cable
Replacement for Intel 8048 microcontroller. Converts the col/row matrix to 5324 scan codes.
DB25 male interface to 5324 via DB25 female-male extension cable.
Unbuffered signals to 5324
Output signals to 5324 are buffered to ensure logic highs are accurately read by the 5324. Input signals are similarly buffered.
Rows pulled high by default, no key press. Will register low when column is scanned and key is pressed.
M3 Mounting Holes
Stabilisers Optional for the FIELD+ key (3u)
12V-to-5V Power Regulation +12V from 5324. LEDs to indicate +12V is available and +5V is working. Use suitable value current limiting resistors as required by your chosen LED. Capacitors for decoupling logic on the keyboard.

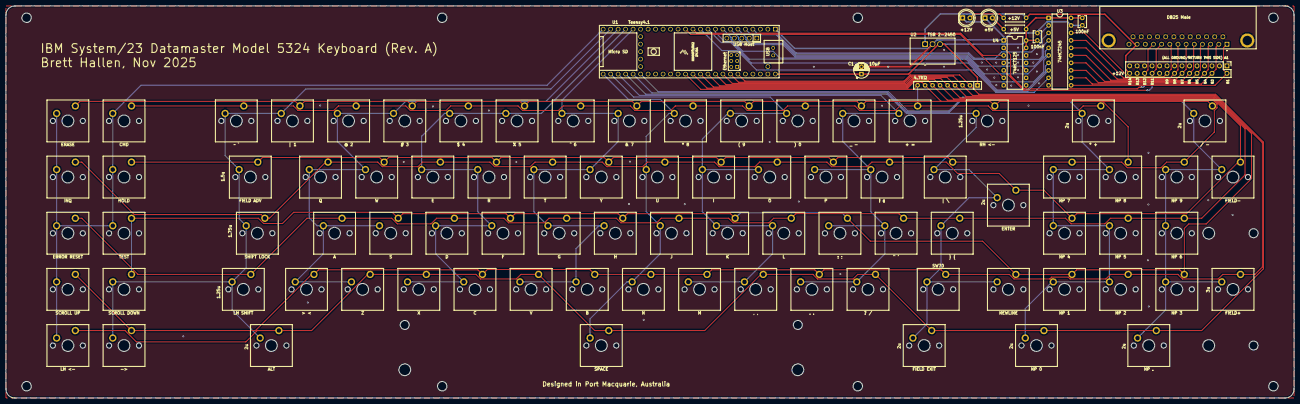
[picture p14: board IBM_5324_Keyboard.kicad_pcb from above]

Board: 2 copper layers, 437.0 x 133.0 mm, 107 parts (0 on the bottom side), 44 nets.

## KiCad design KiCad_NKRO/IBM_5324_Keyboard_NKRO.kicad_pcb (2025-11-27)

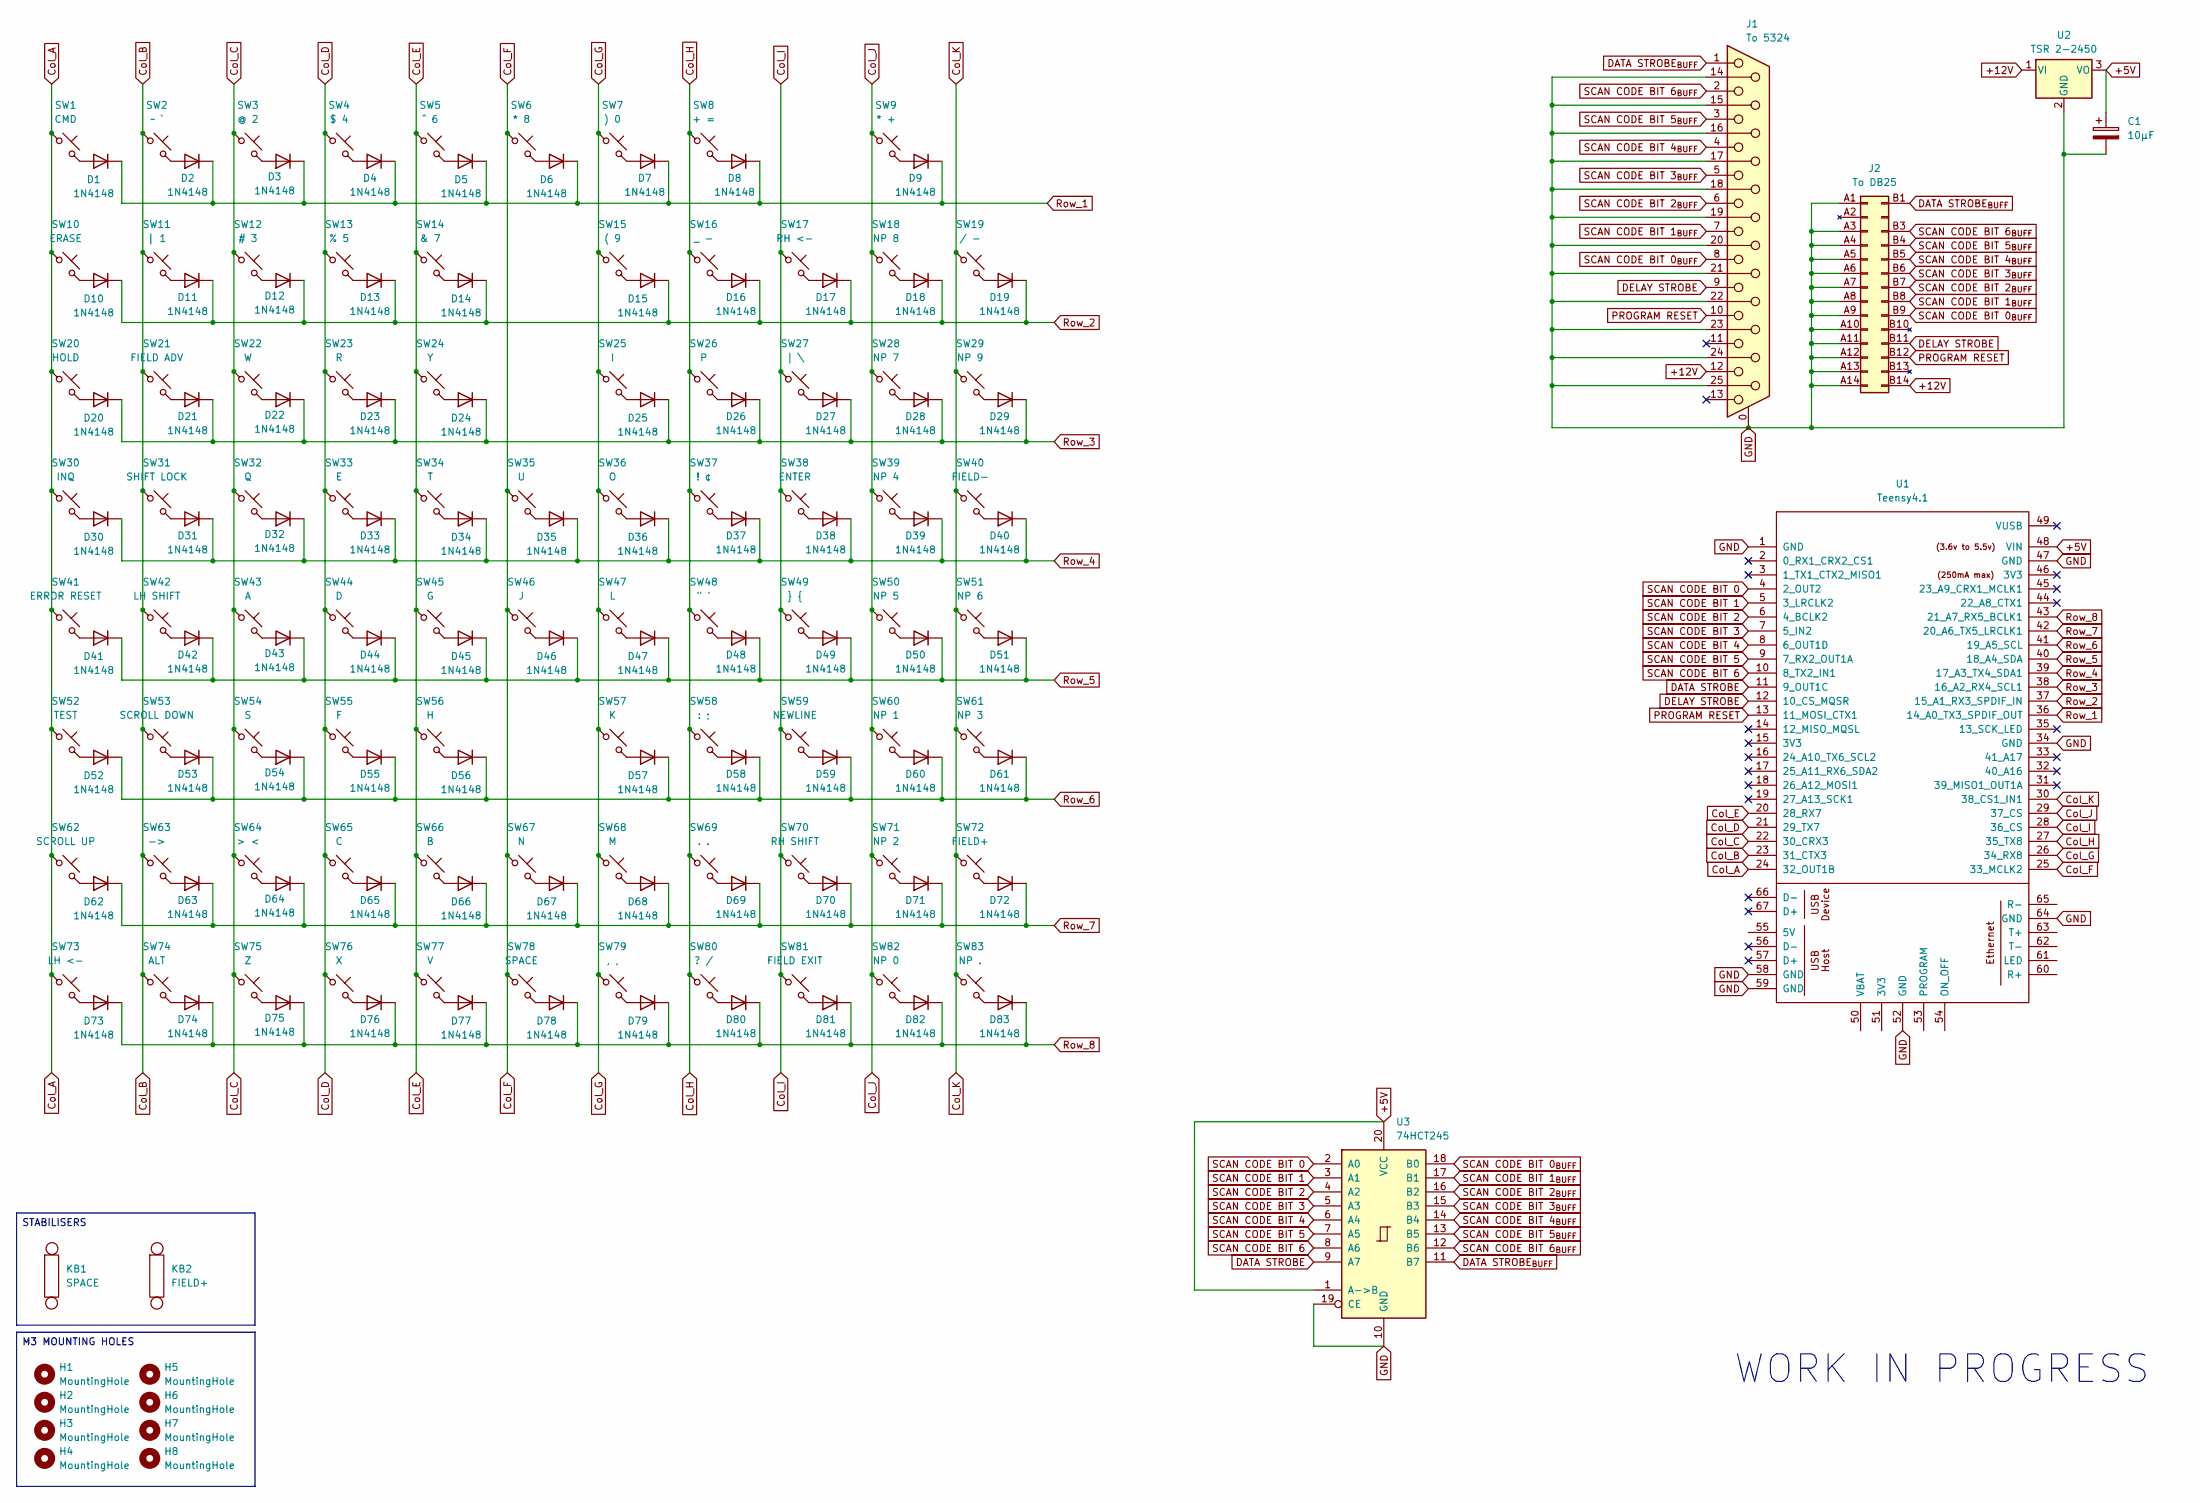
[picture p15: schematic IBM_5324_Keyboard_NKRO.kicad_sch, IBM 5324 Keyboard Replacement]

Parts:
C1: 10µF; CP_Radial_D5.0mm_P2.50mm
D1, D2, D3, D4, D5, D6, D7, D8, D9, D10, D11, D12, D13, D14, D15, D16, D17, D18, D19, D20, D21, D22, D23, D24, D25, D26, D27, D28, D29, D30, D31, D32, D33, D34, D35, D36, D37, D38, D39, D40, D41, D42, D43, D44, D45, D46, D47, D48, D49, D50, D51, D52, D53, D54, D55, D56, D57, D58, D59, D60, D61, D62, D63, D64, D65, D66, D67, D68, D69, D70, D71, D72, D73, D74, D75, D76, D77, D78, D79, D80, D81, D82, D83: 1N4148; D_SOD-123
H1, H2, H3, H4, H5, H6, H7, H8: MountingHole; MountingHole_3.2mm_M3
J1: To 5324; L77SDB25SA4CH4F
J2: To DB25; PinHeader_2x14_P2.54mm_Vertical
KB1: SPACE; Stabilizer_Cherry_MX_8.00u
KB2: FIELD+; Stabilizer_Cherry_MX_3.00u
SW1: CMD; SW_Cherry_MX_PCB
SW2: ~ `; SW_Cherry_MX_PCB
SW3: @ 2; SW_Cherry_MX_PCB
SW4: $ 4; SW_Cherry_MX_PCB
SW5: ^ 6; SW_Cherry_MX_PCB
SW6: * 8; SW_Cherry_MX_PCB
SW7: ) 0; SW_Cherry_MX_PCB
SW8: + =; SW_Cherry_MX_PCB
SW9: * +; SW_Cherry_MX_PCB_1.75u
SW10: ERASE; SW_Cherry_MX_PCB
SW11: | 1; SW_Cherry_MX_PCB
SW12: # 3; SW_Cherry_MX_PCB
SW13: % 5; SW_Cherry_MX_PCB
SW14: & 7; SW_Cherry_MX_PCB
SW15: ( 9; SW_Cherry_MX_PCB
SW16: _ -; SW_Cherry_MX_PCB
SW17: RH <-; SW_Cherry_MX_PCB
SW18: NP 8; SW_Cherry_MX_PCB
SW19: / -; SW_Cherry_MX_PCB_1.75u
SW20: HOLD; SW_Cherry_MX_PCB
SW21: FIELD ADV; SW_Cherry_MX_PCB_1.50u
SW22: W; SW_Cherry_MX_PCB
SW23: R; SW_Cherry_MX_PCB
SW24: Y; SW_Cherry_MX_PCB
SW25: I; SW_Cherry_MX_PCB
SW26: P; SW_Cherry_MX_PCB
SW27: | \; SW_Cherry_MX_PCB
SW28: NP 7; SW_Cherry_MX_PCB
SW29: NP 9; SW_Cherry_MX_PCB
SW30: INQ; SW_Cherry_MX_PCB
SW31: SHIFT LOCK; SW_Cherry_MX_PCB_1.75u
SW32: Q; SW_Cherry_MX_PCB
SW33: E; SW_Cherry_MX_PCB
SW34: T; SW_Cherry_MX_PCB
SW35: U; SW_Cherry_MX_PCB
SW36: O; SW_Cherry_MX_PCB
SW37: ! ¢; SW_Cherry_MX_PCB
SW38: ENTER; SW_Cherry_MX_PCB_2.00u_90deg
SW39: NP 4; SW_Cherry_MX_PCB
SW40: FIELD-; SW_Cherry_MX_PCB
SW41: ERROR RESET; SW_Cherry_MX_PCB
SW42: LH SHIFT; SW_Cherry_MX_PCB_1.25u
SW43: A; SW_Cherry_MX_PCB
SW44: D; SW_Cherry_MX_PCB
SW45: G; SW_Cherry_MX_PCB
SW46: J; SW_Cherry_MX_PCB
SW47: L; SW_Cherry_MX_PCB
SW48: " '; SW_Cherry_MX_PCB
SW49: } {; SW_Cherry_MX_PCB
SW50: NP 5; SW_Cherry_MX_PCB
SW51: NP 6; SW_Cherry_MX_PCB
SW52: TEST; SW_Cherry_MX_PCB
SW53: SCROLL DOWN; SW_Cherry_MX_PCB
SW54: S; SW_Cherry_MX_PCB
SW55: F; SW_Cherry_MX_PCB
SW56: H; SW_Cherry_MX_PCB
SW57: K; SW_Cherry_MX_PCB
SW58: : ;; SW_Cherry_MX_PCB
SW59: NEWLINE; SW_Cherry_MX_PCB
SW60: NP 1; SW_Cherry_MX_PCB
SW61: NP 3; SW_Cherry_MX_PCB
SW62: SCROLL UP; SW_Cherry_MX_PCB
SW63: ->; SW_Cherry_MX_PCB
SW64: > <; SW_Cherry_MX_PCB_1.00u
SW65: C; SW_Cherry_MX_PCB
SW66: B; SW_Cherry_MX_PCB
SW67: N; SW_Cherry_MX_PCB
SW68: M; SW_Cherry_MX_PCB
SW69: . .; SW_Cherry_MX_PCB
SW70: RH SHIFT; SW_Cherry_MX_PCB_1.50u
SW71: NP 2; SW_Cherry_MX_PCB
SW72: FIELD+; SW_Cherry_MX_PCB_3.00u_90deg
SW73: LH <-; SW_Cherry_MX_PCB
SW74: ALT; SW_Cherry_MX_PCB_2.25u
SW75: Z; SW_Cherry_MX_PCB
SW76: X; SW_Cherry_MX_PCB
SW77: V; SW_Cherry_MX_PCB
SW78: SPACE; SW_Cherry_MX_PCB
SW79: , ,; SW_Cherry_MX_PCB
SW80: ? /; SW_Cherry_MX_PCB
SW81: FIELD EXIT; SW_Cherry_MX_PCB_2.00u
SW82: NP 0; SW_Cherry_MX_PCB_2.00u
SW83: NP .; SW_Cherry_MX_PCB_2.00u
U1: Teensy4.1; Teensy41
U2: TSR 2-2450; Converter_DCDC_TRACO_TSR2-24xxN_TSR2-24xxxN_THT
U3: 74HCT245; DIP-18_W7.62mm

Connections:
+5V: C1.1, U1.48 (VIN), U2.3 (VO), U3.1 (A->B), U3.20 (VCC)
+12V: J1.12, J2.B14 (+12V), U2.1 (VI)
Col_A: SW1.1, SW10.1, SW20.1, SW30.1, SW41.1, SW52.1, SW62.1, SW73.1, U1.24 (32_OUT1B)
Col_B: SW2.1, SW11.1, SW21.1, SW31.1, SW42.1, SW53.1, SW63.1, SW74.1, U1.23 (31_CTX3)
Col_C: SW3.1, SW12.1, SW22.1, SW32.1, SW43.1, SW54.1, SW64.1, SW75.1, U1.22 (30_CRX3)
Col_D: SW4.1, SW13.1, SW23.1, SW33.1, SW44.1, SW55.1, SW65.1, SW76.1, U1.21 (29_TX7)
Col_E: SW5.1, SW14.1, SW24.1, SW34.1, SW45.1, SW56.1, SW66.1, SW77.1, U1.20 (28_RX7)
Col_F: SW6.1, SW35.1, SW46.1, SW67.1, SW78.1, U1.25 (33_MCLK2)
Col_G: SW7.1, SW15.1, SW25.1, SW36.1, SW47.1, SW57.1, SW68.1, SW79.1, U1.26 (34_RX8)
Col_H: SW8.1, SW16.1, SW26.1, SW37.1, SW48.1, SW58.1, SW69.1, SW80.1, U1.27 (35_TX8)
Col_I: SW17.1, SW27.1, SW38.1, SW49.1, SW59.1, SW70.1, SW81.1, U1.28 (36_CS)
Col_J: SW9.1, SW18.1, SW28.1, SW39.1, SW50.1, SW60.1, SW71.1, SW82.1, U1.29 (37_CS)
Col_K: SW19.1, SW29.1, SW40.1, SW51.1, SW61.1, SW72.1, SW83.1, U1.30 (38_CS1_IN1)
DATA STROBE: U1.11 (9_OUT1C), U3.9 (A7)
DATA STROBE_{BUFF}: J1.1, J2.B1 (DATA_STROBE), U3.11 (B7)
DELAY STROBE: J1.9, J2.B11 (DELAY_STROBE), U1.12 (10_CS_MQSR)
GND: C1.2, J1.0 (PAD), J1.14, J1.15, J1.16, J1.17, J1.18, J1.19, J1.20, J1.21, J1.22, J1.23, J1.24, J1.25, J2.A1 (GND), J2.A3 (GND), J2.A4 (GND), J2.A5 (GND), J2.A6 (GND), J2.A7 (GND), J2.A8 (GND), J2.A9 (GND), J2.A10 (GND), J2.A11 (GND), J2.A12 (GND), J2.A13 (GND), J2.A14 (GND), U1.1 (GND), U1.34 (GND), U1.47 (GND), U1.52 (GND), U1.58 (GND), U1.59 (GND), U1.64 (GND), U2.2 (GND), U3.10 (GND), U3.19 (CE)
unnamed: D1.2 (A), SW1.2
unnamed: D2.2 (A), SW2.2
unnamed: D3.2 (A), SW3.2
unnamed: D4.2 (A), SW4.2
unnamed: D5.2 (A), SW5.2
unnamed: D6.2 (A), SW6.2
unnamed: D7.2 (A), SW7.2
unnamed: D8.2 (A), SW8.2
unnamed: D9.2 (A), SW9.2
unnamed: D10.2 (A), SW10.2
unnamed: D11.2 (A), SW11.2
unnamed: D12.2 (A), SW12.2
unnamed: D13.2 (A), SW13.2
unnamed: D14.2 (A), SW14.2
unnamed: D15.2 (A), SW15.2
unnamed: D16.2 (A), SW16.2
unnamed: D17.2 (A), SW17.2
unnamed: D18.2 (A), SW18.2
unnamed: D19.2 (A), SW19.2
unnamed: D20.2 (A), SW20.2
unnamed: D21.2 (A), SW21.2
unnamed: D22.2 (A), SW22.2
unnamed: D23.2 (A), SW23.2
unnamed: D24.2 (A), SW24.2
unnamed: D25.2 (A), SW25.2
unnamed: D26.2 (A), SW26.2
unnamed: D27.2 (A), SW27.2
unnamed: D28.2 (A), SW28.2
unnamed: D29.2 (A), SW29.2
unnamed: D30.2 (A), SW30.2
unnamed: D31.2 (A), SW31.2
unnamed: D32.2 (A), SW32.2
unnamed: D33.2 (A), SW33.2
unnamed: D34.2 (A), SW34.2
unnamed: D35.2 (A), SW35.2
unnamed: D36.2 (A), SW36.2
unnamed: D37.2 (A), SW37.2
unnamed: D38.2 (A), SW38.2
unnamed: D39.2 (A), SW39.2
unnamed: D40.2 (A), SW40.2
unnamed: D41.2 (A), SW41.2
unnamed: D42.2 (A), SW42.2
unnamed: D43.2 (A), SW43.2
unnamed: D44.2 (A), SW44.2
unnamed: D45.2 (A), SW45.2
unnamed: D46.2 (A), SW46.2
unnamed: D47.2 (A), SW47.2
unnamed: D48.2 (A), SW48.2
unnamed: D49.2 (A), SW49.2
unnamed: D50.2 (A), SW50.2
unnamed: D51.2 (A), SW51.2
unnamed: D52.2 (A), SW52.2
unnamed: D53.2 (A), SW53.2
unnamed: D54.2 (A), SW54.2
unnamed: D55.2 (A), SW55.2
unnamed: D56.2 (A), SW56.2
unnamed: D57.2 (A), SW57.2
unnamed: D58.2 (A), SW58.2
unnamed: D59.2 (A), SW59.2
unnamed: D60.2 (A), SW60.2
unnamed: D61.2 (A), SW61.2
unnamed: D62.2 (A), SW62.2
unnamed: D63.2 (A), SW63.2
unnamed: D64.2 (A), SW64.2
unnamed: D65.2 (A), SW65.2
unnamed: D66.2 (A), SW66.2
unnamed: D67.2 (A), SW67.2
unnamed: D68.2 (A), SW68.2
unnamed: D69.2 (A), SW69.2
unnamed: D70.2 (A), SW70.2
unnamed: D71.2 (A), SW71.2
unnamed: D72.2 (A), SW72.2
unnamed: D73.2 (A), SW73.2
unnamed: D74.2 (A), SW74.2
unnamed: D75.2 (A), SW75.2
unnamed: D76.2 (A), SW76.2
unnamed: D77.2 (A), SW77.2
unnamed: D78.2 (A), SW78.2
unnamed: D79.2 (A), SW79.2
unnamed: D80.2 (A), SW80.2
unnamed: D81.2 (A), SW81.2
unnamed: D82.2 (A), SW82.2
unnamed: D83.2 (A), SW83.2
PROGRAM RESET: J1.10, J2.B12 (PROGRAM_RESET), U1.13 (11_MOSI_CTX1)
Row_1: D1.1 (K), D2.1 (K), D3.1 (K), D4.1 (K), D5.1 (K), D6.1 (K), D7.1 (K), D8.1 (K), D9.1 (K), U1.36 (14_A0_TX3_SPDIF_OUT)
Row_2: D10.1 (K), D11.1 (K), D12.1 (K), D13.1 (K), D14.1 (K), D15.1 (K), D16.1 (K), D17.1 (K), D18.1 (K), D19.1 (K), U1.37 (15_A1_RX3_SPDIF_IN)
Row_3: D20.1 (K), D21.1 (K), D22.1 (K), D23.1 (K), D24.1 (K), D25.1 (K), D26.1 (K), D27.1 (K), D28.1 (K), D29.1 (K), U1.38 (16_A2_RX4_SCL1)
Row_4: D30.1 (K), D31.1 (K), D32.1 (K), D33.1 (K), D34.1 (K), D35.1 (K), D36.1 (K), D37.1 (K), D38.1 (K), D39.1 (K), D40.1 (K), U1.39 (17_A3_TX4_SDA1)
Row_5: D41.1 (K), D42.1 (K), D43.1 (K), D44.1 (K), D45.1 (K), D46.1 (K), D47.1 (K), D48.1 (K), D49.1 (K), D50.1 (K), D51.1 (K), U1.40 (18_A4_SDA)
Row_6: D52.1 (K), D53.1 (K), D54.1 (K), D55.1 (K), D56.1 (K), D57.1 (K), D58.1 (K), D59.1 (K), D60.1 (K), D61.1 (K), U1.41 (19_A5_SCL)
Row_7: D62.1 (K), D63.1 (K), D64.1 (K), D65.1 (K), D66.1 (K), D67.1 (K), D68.1 (K), D69.1 (K), D70.1 (K), D71.1 (K), D72.1 (K), U1.42 (20_A6_TX5_LRCLK1)
Row_8: D73.1 (K), D74.1 (K), D75.1 (K), D76.1 (K), D77.1 (K), D78.1 (K), D79.1 (K), D80.1 (K), D81.1 (K), D82.1 (K), D83.1 (K), U1.43 (21_A7_RX5_BCLK1)
SCAN CODE BIT 0: U1.4 (2_OUT2), U3.2 (A0)
SCAN CODE BIT 0_{BUFF}: J1.8, J2.B9 (SCAN_CODE_BIT_0), U3.18 (B0)
SCAN CODE BIT 1: U1.5 (3_LRCLK2), U3.3 (A1)
SCAN CODE BIT 1_{BUFF}: J1.7, J2.B8 (SCAN_CODE_BIT_1), U3.17 (B1)
SCAN CODE BIT 2: U1.6 (4_BCLK2), U3.4 (A2)
SCAN CODE BIT 2_{BUFF}: J1.6, J2.B7 (SCAN_CODE_BIT_2), U3.16 (B2)
SCAN CODE BIT 3: U1.7 (5_IN2), U3.5 (A3)
SCAN CODE BIT 3_{BUFF}: J1.5, J2.B6 (SCAN_CODE_BIT_3), U3.15 (B3)
SCAN CODE BIT 4: U1.8 (6_OUT1D), U3.6 (A4)
SCAN CODE BIT 4_{BUFF}: J1.4, J2.B5 (SCAN_CODE_BIT_4), U3.14 (B4)
SCAN CODE BIT 5: U1.9 (7_RX2_OUT1A), U3.7 (A5)
SCAN CODE BIT 5_{BUFF}: J1.3, J2.B4 (SCAN_CODE_BIT_5), U3.13 (B5)
SCAN CODE BIT 6: U1.10 (8_TX2_IN1), U3.8 (A6)
SCAN CODE BIT 6_{BUFF}: J1.2, J2.B3 (SCAN_CODE_BIT_6), U3.12 (B6)

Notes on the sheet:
WORK IN PROGRESS
M3 MOUNTING HOLES
STABILISERS

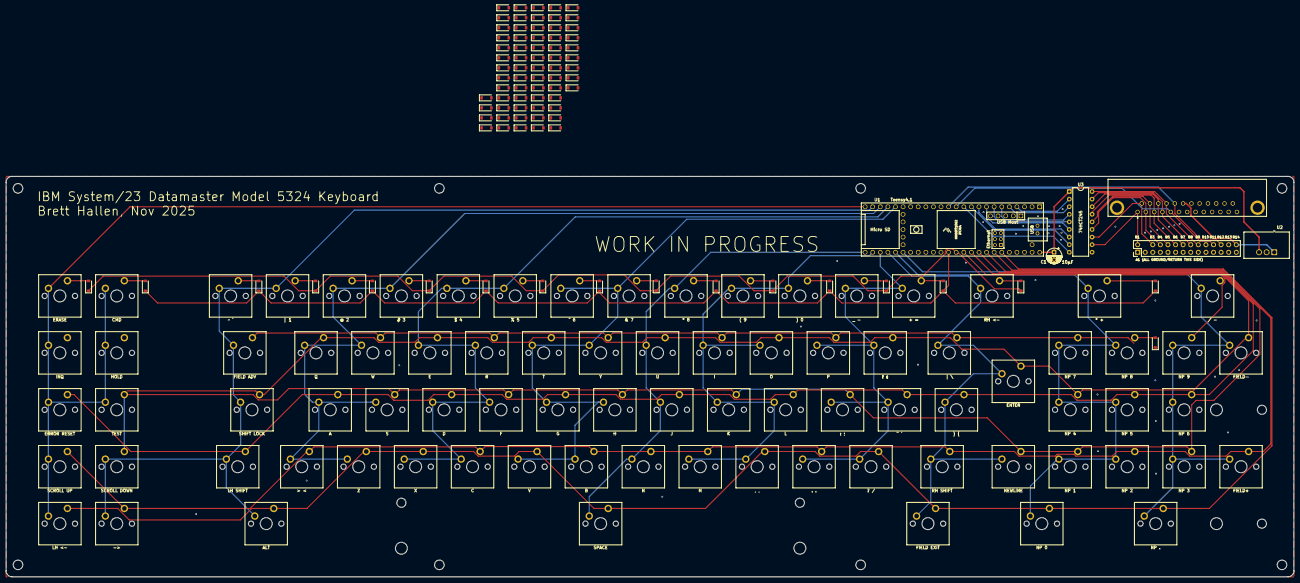
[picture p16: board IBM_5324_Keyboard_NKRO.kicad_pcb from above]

Board: 2 copper layers, 431.0 x 134.0 mm, 182 parts (0 on the bottom side), 123 nets.

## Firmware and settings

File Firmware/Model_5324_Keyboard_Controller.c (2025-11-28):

// IBM System/23 Model 5324 Keyboard Controller
// Scan 11 columns, read 8 rows, output 7-bit scan code
// Brett Hallen, Nov 2025
// Port Macquarie, Australia

// WORK IN PROGRESS - WORK IN PROGRESS - WORK IN PROGRESS - WORK IN PROGRESS - WORK IN PROGRESS
/*
   IBM System/23 Model 5324 keyboard scan codes
   +----+----+    +----+----+----+----+----+----+----+----+----+----+----+----+----+----+---------+---------+
   | 7C | 6F |    | 3E | 31 | 32 | 33 | 34 | 35 | 36 | 37 | 38 | 39 | 3A | 3B | 3C | 3D |    4B   |   4C    |
   |    | 7F |    |    |    |    |    |    |    |    |    |    |    |    |    |    |1   |         |         |
   +----+----+    +----+----+----+----+----+----+----+----+----+----+----+----+----+----+----+----+----+----+
   | 6C | 6D |    | 20 | 21 | 22 | 23 | 24 | 25 | 26 | 27 | 28 | 29 | 2A | 2B | 2C | 2D | 47 | 48 | 49 | 4E |
   +----+----+    +----+----+----+----+----+----+----+----+----+----+----+----+----+    +----+----+----+----+
   | 6E | 7D |    | 54 | 11 | 12 | 13 | 14 | 15 | 16 | 17 | 18 | 19 | 1A | 1B | 59 |    | 44 | 45 | 46 | 4D |
   |    |    |    | 74 |    |    |    |    |    |    |    |    |    |    |    | 79 |    |    |    |    |    |
   +----+----+    +----+----+----+----+----+----+----+----+----+----+----+----+----+----+----+----+----+    |
   | 71 | 70 |    | OE | 01 | 02 | 03 | 04 | 05 | 06 | 07 | 08 | 09 | 0A |   0B    | 56 | 41 | 42 | 43 |    |
   |    |    |    |    |    |    |    |    |    |    |    |    |    |    |   7B    | 76 |    |    |    |    |
   +----+----+    +----+----+----+----+----+----+----+----+----+----+----+----+----+----+----+----+----+    |
   | 72 | 73 |    | 7E |                              0F                      | 68 |    40   |   4A    |    |
   |    |    |    | 5E |                                                      | 78 |         |         |    |
   |----+----+    +----+----+----+----+----+----+----+----+----+----+----+----+----+---------+---------+----+
   
   Typamatic scan codes:
   0F
   3D
   70
   71
   72
   73
*/

const int NUM_COLS = 11;
const int NUM_ROWS = 8;
const int colPins[NUM_COLS] = {24,23,22,21,20,25,26,27,28,29,30}; // Columns A-K
const int rowPins[NUM_ROWS] = {36,37,38,39,40,41,42,43};           // Rows 1-8
const int bitPins[7] = {4,5,6,7,8,9,10};                           // Scan code bits 0-6 (LSB first)
const int dataStrobePin = 11;                                      // Pulse low on new code
const int delayStrobePin = 12;                                     // System ACK (input, optional)
const int resetPin = 13;                                           // System reset (input)

// Scan code lookup table
// 0x00 marks unused code
byte scanCode[NUM_ROWS][NUM_COLS] = 
{
  // Column  A     B     C     D     E     F     G     H     I     J     K
  // Row 1: CMD     ~`   @2    $4    ^6    *8    )0    +=          *+
           {0x6F, 0x3E, 0x32, 0x34, 0x36, 0x38, 0x3A, 0x3C, 0x00, 0x4B, 0x00},
  // Row 2: ERASE  |1    #3    %5    &7          (9    _-   <--    8     /- 
           {0x7C, 0x31, 0x33, 0x35, 0x37, 0x00, 0x39, 0x3B, 0x3D, 0x48, 0x4C},
  // Row 3: HOLD  TAB    W     R     Y           I     P     |\    7     9
           {0x6D, 0x20, 0x22, 0x24, 0x26, 0x00, 0x28, 0x2A, 0x2C, 0x47, 0x49},
  // Row 4: INQ,  CAPS   Q     E     T     U     O     !¢  ENTER   4    Field -
           {0x6C, 0x54, 0x21, 0x23, 0x25, 0x27, 0x29, 0x2B, 0x2D, 0x44, 0x4E}, 
  // Row 5: ERROR Shift  A     D     G     J     L     "'    }{    5     6
           {0x6E, 0x57, 0x11, 0x13, 0x15, 0x17, 0x19, 0x1B, 0x59, 0x45, 0x46},  
  // Row 6: TEST  ScrDn  S     F     H           K     :;    NL    1     3
           {0x7D, 0x70, 0x12, 0x14, 0x16, 0x00, 0x18, 0x1A, 0x56, 0x41, 0x43},
  // Row 7: ScrUp  -->   ><    C     B     N     M     .    Shift  2    Field +
           {0x71, 0x73, 0x0E, 0x03, 0x05, 0x06, 0x07, 0x09, 0x0B, 0x42, 0x4D},
  // Row 8: <--   ALT    Z     X     V    SPACE  ,     ?    EXIT   0     .
           {0x72, 0x7E, 0x01, 0x02, 0x04, 0x0F, 0x08, 0x0A, 0x68, 0x40, 0x4A} 
};

// Key state tracking
bool prevState[NUM_ROWS][NUM_COLS];
unsigned long lastTypamatic[NUM_ROWS][NUM_COLS];

// Typamatic lookup table (marked **, repeat while held)
// Typamatic key is non-zero
byte isTypamatic[NUM_ROWS][NUM_COLS] = 
{
  // Column A     B     C     D     E     F     G     H     I     J     K
          {0x00, 0x00, 0x00, 0x00, 0x00, 0x00, 0x00, 0x00, 0x00, 0x00, 0x00 }, // Row 1
          {0x00, 0x00, 0x00, 0x00, 0x00, 0x00, 0x00, 0x00, 0x01, 0x00, 0x00 }, // Row 2
          {0x00, 0x00, 0x00, 0x00, 0x00, 0x00, 0x00, 0x00, 0x00, 0x00, 0x00 }, // Row 3
          {0x00, 0x00, 0x00, 0x00, 0x00, 0x00, 0x00, 0x00, 0x00, 0x00, 0x00 }, // Row 4
          {0x00, 0x00, 0x00, 0x00, 0x00, 0x00, 0x00, 0x00, 0x00, 0x00, 0x00 }, // Row 5
          {0x00, 0x01, 0x00, 0x00, 0x00, 0x00, 0x00, 0x00, 0x00, 0x00, 0x00 }, // Row 6
          {0x01, 0x01, 0x00, 0x00, 0x00, 0x00, 0x00, 0x00, 0x00, 0x00, 0x00 }, // Row 7
          {0x01, 0x00, 0x00, 0x00, 0x00, 0x01, 0x00, 0x00, 0x00, 0x00, 0x00 }  // Row 8
};

// Scan code lookup table for make/break keys (marked *, send on release)
byte makeBreakScanCode[NUM_ROWS][NUM_COLS] = 
{
  // Column A     B     C     D     E     F     G     H     I     J     K
          {0x7F, 0x00, 0x00, 0x00, 0x00, 0x00, 0x00, 0x00, 0x00, 0x00, 0x00 }, // Row 1
          {0x00, 0x00, 0x00, 0x00, 0x00, 0x00, 0x00, 0x00, 0x00, 0x00, 0x00 }, // Row 2
          {0x00, 0x00, 0x00, 0x00, 0x00, 0x00, 0x00, 0x00, 0x00, 0x00, 0x00 }, // Row 3
          {0x00, 0x74, 0x00, 0x00, 0x00, 0x00, 0x00, 0x00, 0x00, 0x00, 0x00 }, // Row 4
          {0x00, 0x77, 0x00, 0x00, 0x00, 0x00, 0x00, 0x00, 0x79, 0x00, 0x00 }, // Row 5
          {0x00, 0x00, 0x00, 0x00, 0x00, 0x00, 0x00, 0x00, 0x76, 0x00, 0x00 }, // Row 6
          {0x00, 0x00, 0x00, 0x00, 0x00, 0x00, 0x00, 0x00, 0x7B, 0x00, 0x00 }, // Row 7
          {0x00, 0x5E, 0x00, 0x00, 0x00, 0x00, 0x00, 0x00, 0x78, 0x00, 0x00 }  // Row 8
};

void setup() 
{
  Serial.begin(38400);
  for (int i = 0; i < NUM_COLS; i++) 
  {
    pinMode(colPins[i], OUTPUT);
    digitalWrite(colPins[i], HIGH);  // Inactive high
  }
  for (int i = 0; i < NUM_ROWS; i++) 
  {
    pinMode(rowPins[i], INPUT_PULLUP);
  }
  for (int i = 0; i < 7; i++) 
  {
    pinMode(bitPins[i], OUTPUT);
    digitalWrite(bitPins[i], LOW);  // Idle low
  }
  pinMode(dataStrobePin, OUTPUT);
  digitalWrite(dataStrobePin, HIGH);  // Idle high
  pinMode(delayStrobePin, INPUT_PULLUP);  // Optional system ACK
  pinMode(resetPin, INPUT_PULLUP);
  // Init states
  memset(prevState, 0, sizeof(prevState));
  // Pulse reset on startup if needed
  if (digitalRead(resetPin) == LOW)
  	resetKeyboard();
  Serial.println("IBM 5324 Keyboard Emulator Ready");
}

void loop() 
{
  // Check for system reset
  if (digitalRead(resetPin) == LOW) 
  {
    resetKeyboard();
    delay(100);
  }

  bool keyActive = false;
  for (int c = 0; c < NUM_COLS; c++) 
  {
    digitalWrite(colPins[c], LOW);  // Drive column low
    delayMicroseconds(10);  // Settle time

    for (int r = 0; r < NUM_ROWS; r++) 
    {
      bool pressed = (digitalRead(rowPins[r]) == LOW);  // Active low
      if (pressed != prevState[r][c]) 
      {
        if (pressed) 
        {
          handleKeyPress(r, c);
        } 
        else if (isMakeBreak[r][c]) 
        {
          handleKeyRelease(r, c);  // Send on release for * keys
        }
        prevState[r][c] = pressed;
        keyActive = true;
      } 
      else if (pressed && isTypamatic[r][c]) 
      {
        // Typamatic repeat
        unsigned long now = millis();
        if (now - lastTypamatic[r][c] > 100) 
        {  // 100ms repeat rate
          handleKeyPress(r, c);
          lastTypamatic[r][c] = now;
        }
      }
    }
    digitalWrite(colPins[c], HIGH);  // Release column
  }

  if (!keyActive) 
  {
    // Idle: clear bits?
    setScanCode(0x00);
  }
  delay(10);  // Scan rate ~100Hz, debounce
}

void handleKeyPress(int row, int col) 
{
  byte code = scanCodes[row][col];
  if (code != 0x00) 
  {
    sendScanCode(code);
    if (isTypamatic[row][col]) 
    	lastTypamatic[row][col] = millis();
    Serial.print("Key pressed (R"); Serial.print(row+1); Serial.print(" C"); Serial.print(col+1);
    Serial.print("): 0x"); Serial.println(code, HEX);
  }
}

void handleKeyRelease(int row, int col) 
{
  byte code = scanCodes[row][col];
  if (code != 0x00) 
  {
    sendScanCode(code);  // Or invert: sendScanCode(code | 0x80); if system expects break
    Serial.print("Key released (R"); Serial.print(row+1); Serial.print(" C"); Serial.print(col+1);
    Serial.print("): 0x"); Serial.println(code, HEX);
  }
}

void sendScanCode(byte code) 
{
  setScanCode(code);
  // Pulse DATA STROBE (system interrupt)
  digitalWrite(dataStrobePin, LOW);
  delayMicroseconds(50);  // Match original timing
  digitalWrite(dataStrobePin, HIGH);
  // Optional: Wait for DELAY STROBE ACK
  // while (digitalRead(delayStrobePin) == HIGH) {}  // Block until low
}

void setScanCode(byte code) 
{
  for (int b = 0; b < 7; b++) 
  {
    digitalWrite(bitPins[b], (code & (1 << b)) ? HIGH : LOW);
  }
}

void resetKeyboard() 
{
  setScanCode(0x00);
  // Clear typamatic timers, etc.
  memset(lastTypamatic, 0, sizeof(lastTypamatic));
  Serial.println("Keyboard Reset");
}

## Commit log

2025-11-26 Further work
    [IBM_5324_Keyboard.kicad_sch]
2025-11-27 Progressing design
    [IBM_5324_Keyboard.kicad_pcb, IBM_5324_Keyboard.kicad_sch]
2025-11-27 Key switch routing completed
    [IBM_5324_Keyboard.kicad_pcb, IBM_5324_Keyboard.kicad_sch]
2025-11-27 Started work on firmware
    [IBM_5324_Keyboard.kicad_pcb, IBM_5324_Keyboard.kicad_sch]
2025-11-27 Started firmware development
    [IBM_5324_Keyboard.kicad_pcb, IBM_5324_Keyboard.kicad_sch]
2025-11-27 Design tweaks
    [IBM_5324_Keyboard.kicad_pcb, IBM_5324_Keyboard.kicad_sch]
2025-11-28 Swapped DB25 female to male
    [IBM_5324_Keyboard.kicad_pcb, IBM_5324_Keyboard.kicad_sch]
2025-11-28 Added external pull-up array on rows
    [IBM_5324_Keyboard.kicad_pcb, IBM_5324_Keyboard.kicad_pcb_bom.csv, IBM_5324_Keyboard.kicad_pcb_positions.csv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]
2025-11-28 Revised schematic & PCB layout
    [IBM_5324_Keyboard.kicad_pcb, IBM_5324_Keyboard.kicad_pcb_bom.csv, IBM_5324_Keyboard.kicad_pcb_positions.csv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]
2025-11-29 Modified to indicate signals are active LOW
    [IBM_5324_Keyboard.kicad_sch]
2025-11-29 Further refinements to PCB layout
    - missing value text on some parts
    - isolated ground on 74LS245
    [IBM_5324_Keyboard.kicad_pcb, IBM_5324_Keyboard.kicad_pcb_bom.csv, IBM_5324_Keyboard.kicad_pcb_positions.csv]
